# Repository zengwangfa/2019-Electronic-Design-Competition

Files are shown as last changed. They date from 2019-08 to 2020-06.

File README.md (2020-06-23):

# 纸张计数显示装置😄

<p align="center">
  <a href="/docs/论文/纸张计数显示器论文.md">电赛论文📚|</a>
  <a href="/software/">软件说明💻|</a>
  <a href="/mechanical/">机械说明🎮|</a>
  <a href="/hmi/">交互界面说明🖼|</a>
  <a href="/综合测评/">综合测评📐</a>
</p>

---

<p align="center">
  
</p>

<p align="center">
  
  
  
</p>

## 1、简介:pencil2:
>纸张计数显示装置基于**RT-Thread**实时操作系统，硬件平台采用**STM32F407**单片机为主控制器，以具有抗电磁干扰（**EMI**）架构的FDC2214模块作为电容采集传感器，通过**屏蔽双绞线**连接至两铜极板，读取采集的数据并进行相应判断，应用触摸屏和语音模块进行状态显示与播报。FDC2214模块将采集到的数据通过IIC协议传输给主控制器，主控制器对原始数据进行**卡尔曼滤波**，抑制噪声对数据采集的影响。校准模式下，本系统利用最大隶属度法，确定电容模拟值及纸张数的论域，定义模糊子集和隶属函数，建立模糊规则控制表，求得模糊控制查询表。其根据采集到的两极板的数据，做出短路判断并读取多组实时数据，将其与模拟区间进行归类，选取**最大可能性区间**作为期望值，减小最终判断的差错率。

- [x] 成果：在校准好后，50张以下`100%`正确

---

| 配置参数 | 主控制器 | 配置参数 | 主传感器 |
| :--: | :--: | :--: | :--: |
|芯片型号| STM32F407ZGT6 |芯片型号| FCD2214 |
|CPU| 32位 Cortex-M4(ARMv7) |分辨率| 28位 |
|主频| 168MHz |通道数| 4 |
|RAM| 192KB |接口| I2C |
|外存| 1MB(FLASH) |最高输出速率| 4.08ksps |
|单元| FPU、DSP | 特性 |抗电磁干扰(EMI) |

---

- 系统结构简图：
系统结构简图

## 2、目录说明:bookmark:

#### STM32F407控制程序在：
```
+——2019-Electronic-Design-Competition
|---+ software:【软件设计】
|       ├──README.md
|       ├──rt-thread-master
|            └──bsp
|               └──stm32f407【控制程序】
|                  └──project.uvprojx【Keil5工程】
|---- ...

```
| 目录名 | 描述  |
| :---: | :---: |
| 2019电赛题目| 2019年电赛A-H题题目及器件清单 |
| [docs](./docs/) | 数据手册、设计图片、参考文献及设计文档 |
| [hardware](./hardware/) | FDC2214、核心板原理图及PCB |
| hmi| 串口屏幕设计UI及交互程序、语音包 |
| matlab| matlab函数拟合及Kalman  |
| mechanical | 机械结构设计 |
| others | 一些关于电赛前的准备 |
| [**software**](./software/) | **纸张计数显示装置STM32程序** |
| [综合测评](./综合测评/) | **综合测评题目及Multisim电路仿真** |

## 3、[机械结构:hammer:](/mechanical/)
- 3维模型
3D效果图
- 实物图
铰链结构实物图

## 4、[软件说明💻](/software/) 

应用线程总体分为：
- 1.简单设备运行线程
    - LED
	- OLED
	- Buzzer
	- Flash
	
- 2.主测量应用线程
	- HMI屏幕交互
	- FD2214数据获取与转换
	- 语音模块交互
	
- 3.系统监控线程
	- Watch Dog:dog2:

## 5、硬件结构:artificial_satellite:

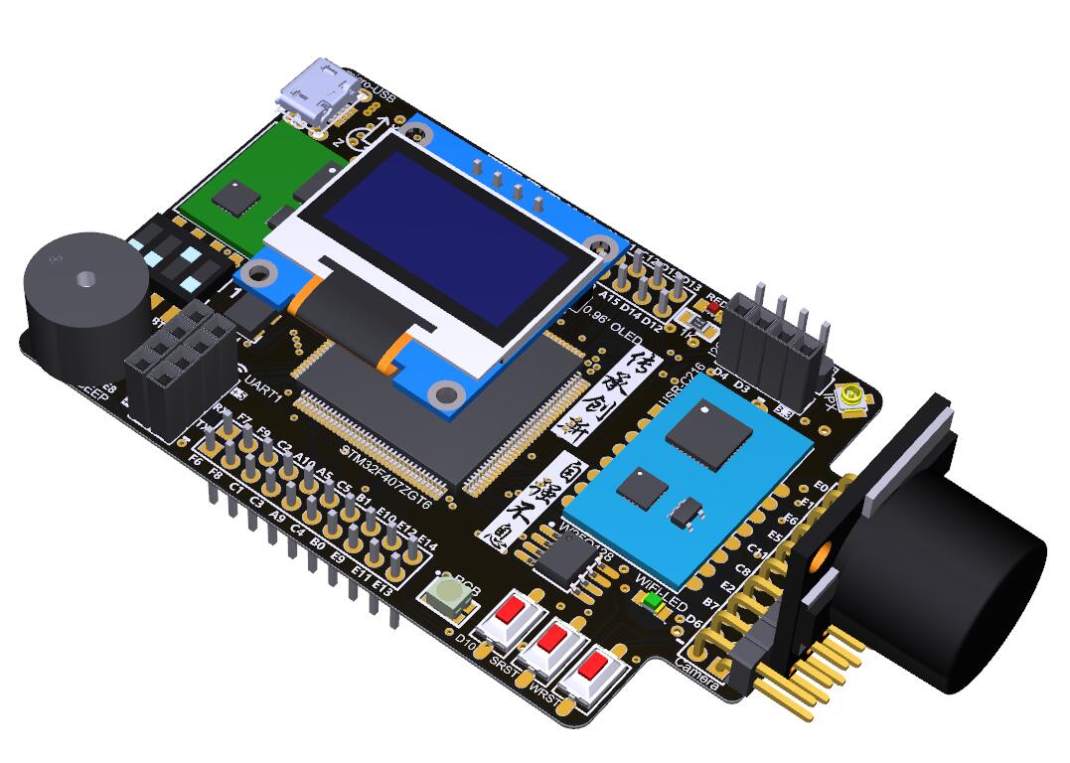
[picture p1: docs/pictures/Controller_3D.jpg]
Controller PCB 3D Core Controller 3D


- 核心板(Core Controller)拥有外设：

| 外设名称 | RGB LED | Key | Buzzer | Dial Switch | **FCD2214** | USART HMI |OLED | W25Q128 | Voltage Detection | Current Detection | Zigbee |  JY901 | USR-C216 | CP2102 |
| :---: | :---: | :---: | :---: | :---: | :---: | :---: | :---: | :---: | :---: | :---: | :---: | :---: | :---: |  :---: |
| 控制(通讯)方式 | GPIO | GPIO | GPIO | GPIO | **I2C** | USART | SPI | SPI | ADC | ADC | USART | USART | USART  | USART |
| 功能描述 | 指示灯 | 按键 | 蜂鸣器 | 拨码开关 | **电容传感器** | 串口触摸屏 | 显示屏 | 闪存芯片 | 电压检测 | 电流检测 | 2.4G无线通信 | 九轴 | WiFi模块 | 串口转USB |

- 整体实物图
整体实物图

---
## 6、[交互界面:framed_picture:](/hmi/) 

- [x] 电脑调试时的交互界面展示：

<p align="center">
  
</p>

## 7、测试数据分析:bar_chart:

(1)
保持测试环境不变，采集50个样本，通过MATLAB拟合出纸张页数与传感器原始数据的曲线关系，如图4-2所示。

拟合曲线

**图4-2 纸张页数与模拟量的拟合函数关系图**

- (2) 根据(1)中采集的50个样本，确定电容模拟值及纸张数的论域，划分模糊子集，如表4-1
所示。

**表4-1页数与模拟量区间对应表**

| 页数/张 | 对应模拟量区间 | 页数/张 | 对应模拟量区间  |
|---|---|---|---|
| 1 | [1680.00,1345.34] | 6 | [682.48,633.84] |
| 2 | [1345.34,1013.26] | 7 | [633.84,598.03] |
| 3 | [1013.26,845.12]  | 8 | [598.03,569.46] |
| 4 | [845.12,748.79] | 9 | [569.46,546.28] |
| 5 | [748.79,682.48] | 10 | [546.28,529.16] |

- (3)根据（2）中划分的模糊子集，保持测试环境不变，固定测量35张纸张，采集数据如表4-2所示，采集到的原始数据90%落入35张页数所对应的区间[401.35,399.50]，如图4-35

35张纸区间图 35页落点区间

**表4-2 纸张数为35的实时数据**

| 测试组别 | 原始数据 | 测试组别 | 原始数据 |
|---|---|---|---|
| 1 | 400.896  | 6 | 400.824  |
| 2 | 401.049  | 7 | 400.591  |
| 3 | 400.157  | 8 | 401.111  |
| 4 | 399.912  | 9 | 400.443  |
| 5 | 401.125  | 10 | 398.529  |

- 测试结果

**表4-4 工作模式下纸张测试结果表**

| 范围 | 测试次数 | 正确次数 | 正确率 |
|---|---|---|---|
| 1\~10  | 25 | 25 | 100% |
| 11\~20 | 25 | 25 | 100% |
| 20\~30 | 25 | 25 | 100% |
| 30\~40 | 25 | 25 | 100% |
| 40\~50 | 25 | 25 | 100% |
| 50\~60 | 25 | 23 | 92% |
| 60\~70 | 25 | 20 | 80% |
| 70\~80 | 25 | 16 | 64% |

## 8、[综合测评演练:triangular_ruler:](/综合测评/)
- 选定2017综合测评题目【符合信号发生器】，进行综合测评训练
2017年全国大学生电子设计竞赛综合测评题训练结果 2017年全国大学生电子设计竞赛综合测评题

虽然测评训练的时候做的还行，但是实际当天综测比赛的时候，还是会手忙脚乱，现在想起那天焊接电路颤抖的双手都有点好笑:rofl::rofl:。
- 综测训练测试结果：
2017综测训练

## 9、分工:family:
- [X] 电路设计
    - [X] 硬件搭建 by [@Ian](https://github.com/zengwangfa)	
	
- [X] 控制程序
    - [X] 整体框架 by [@Ian](https://github.com/zengwangfa)
	- [x] 交互界面及通信 by [@Ian](https://github.com/zengwangfa)
	- [X] 核心分割算法 by [@Okurarisona](https://github.com/Okurarisona)

- [X] 机械结构
	- [X] 结构方案设计 by [@JackyLin](https://github.com/JackyLin1205) 
	- [X] 固定铰链式抗干扰结构 by [@JackyLin](https://github.com/JackyLin1205) 

- [X] 论文
	- [X] 论文 by [@Hyf338](https://github.com/Hyf338)

#### Github下载过慢
- [Github下载过慢解决办法](https://blog.csdn.net/wangshuaiwsws95/article/details/104730741/)

#### 整理纪念
- [点击联系我](Mailto:zengwangfa@outlook.com)

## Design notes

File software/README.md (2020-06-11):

#### STM32F407控制程序在：
```
|---+ software:【软件设计】
|       ├──README.md
|       ├──rt-thread-master
|            └──bsp
|               └──stm32f407【控制程序】
|                  └──project.uvprojx【Keil5工程】
|---- ...

```

## 1. 程序描述与思路:book:

### 1.1 系统总体工作流程

> 软件部分主要分成用户交互设计以及数据处理算法设计，基于RT-Thread实时操作系统，利用系统的线程调度完成各个模块的程序处理，应用线程总体分为：

- 1.简单设备运行线程
    - LED
	- OLED
	- Buzzer
	- Flash
	
- 2.主测量引用线程
	- HMI屏幕交互
	- FD2214数据获取与转换
	- 语音模块交互
	
- 3.系统监控线程
	- Watch Dog

### 1.2 程序设计思路

> 在整体软件中，首先在触摸屏菜单进行人机交互，进入不同的功能调用不同的控制函数与数据处理算法。程序线程调度，主要分为简单任务以及核心算法算法任务。简单任务为IO设备、触摸屏、OLED屏幕、语音模块、NB-IOT模块等设备控制；核心控制算法任务为FDC2214电容模拟值采集、卡尔曼滤波以及模糊求解最大可能性落点区间，从而得到当前纸张数量。

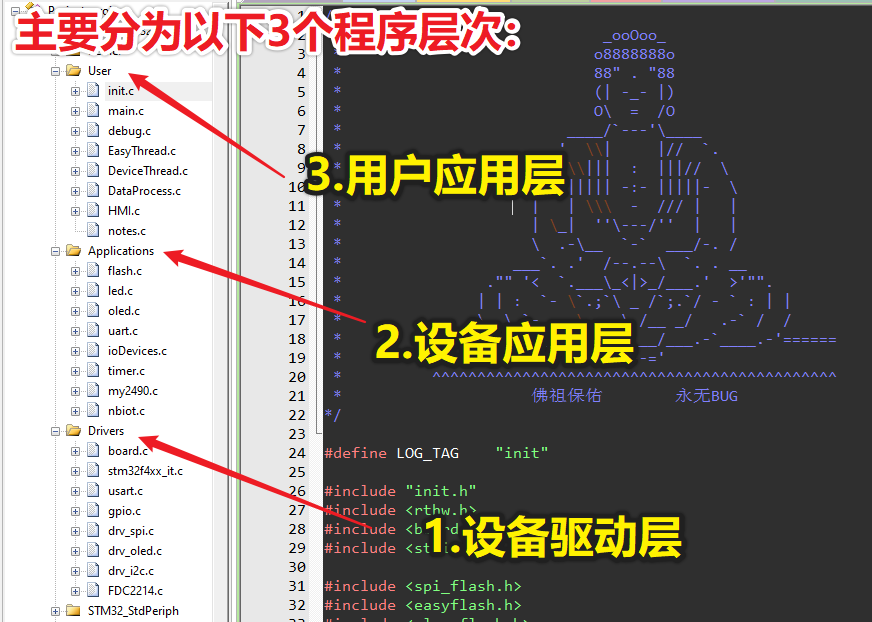
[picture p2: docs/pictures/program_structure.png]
程序结构


- [x] 1.首先在`设备驱动层`中构建好设备的底层硬件驱动程序，以供中层的`设备应用层`调用
- [x] 2.其次在`设备应用层`封装好相应的设备应用程序，留好相应的接口，以供上层`用户应用层`调用，例如：
	- **RGB LED**控制调用（参数：模式、颜色）
	- **蜂鸣器**控制调用（参数：响几声、响多长）
	- **语音模块**控制调用（参数：语音内容）
	- **OLED**控制调用（函数：显示对应的模式内容）
	- **Flash**控制调用（函数：读写参数）
	- **Uart**控制调用（函数：数据接收回调）
	- **FDC2214**控制调用（函数：获取电容值）
- [x] 3.最后在`用户应用层`中进行相应的**3.1 调试工具**、**3.2 模块交互封装**以及**3.3 数据处理**。

---
- 3.1 【调试工具】 在`debug.c`其中存放的为山外上位机示波器数据发送函数，用来分析数据较为合适。
	- eg:[这张图片是在调试PID与角度响应时所记录](../docs/pictures/debug.png "PID_debug")

- 3.2 【模块交互封装】 在`HMI.c`其中存放的为串口触摸屏的数据交互函封装(其中最重要的为：串口屏数据解析函数`HMI_Data_Analysis()`)

- 3.3 【数据处理】 最重要的为`DeviceThread.c`，其中存放工作模式的选择、运行线程以及调试
	- 1.数据校准：`FDC2214_Data_Adjust()`
	- 2.工作模式:`Capcity_Paper_Detection()`
	- 3.扩展功能模式：
		- ①打印机 纸张检测：`Printer_Paper_Detection()`
		- ②材料 检测：`Material_Detection()`
		- ③纸币 检测：`Money_Detection()`

- 工作模式选择，其与OLED页面对应
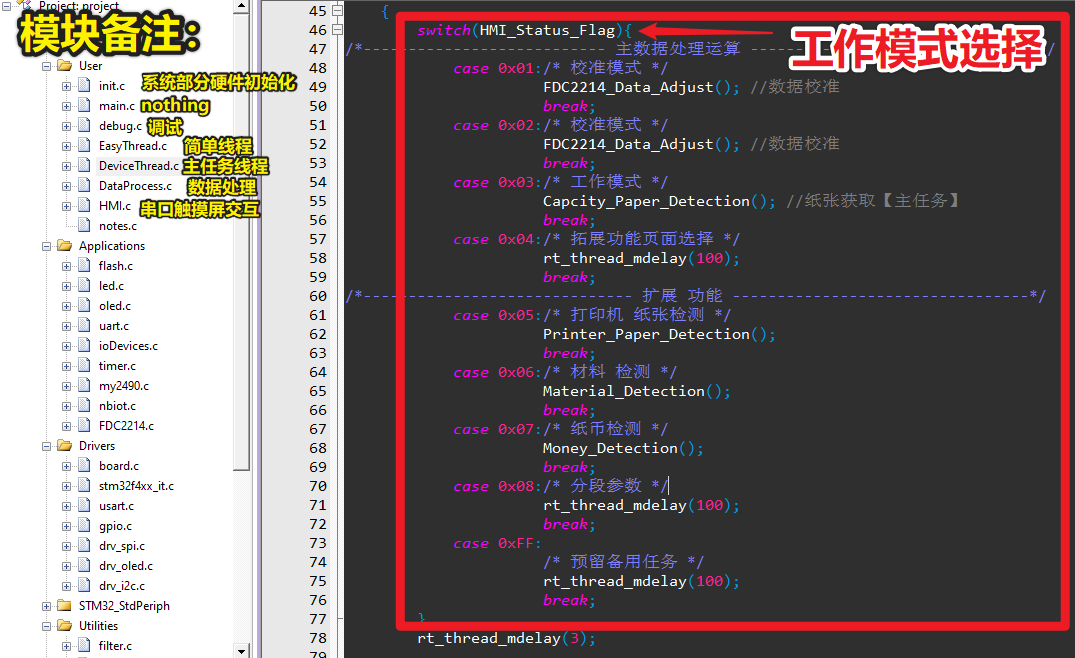
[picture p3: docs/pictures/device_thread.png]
工作模式选择


> 工作模式的选择来自于 变量`HMI_Status_Flag`，其为解析 触摸屏按钮所发出的数据包，而获得的工作模式。

## 2. 纸张数量程序的具体实现
### 2.1 获取电容值

1.首先准备就绪后，构建系统工作的参数结构体：
```c
typedef struct
{
	uint8 Status;      //检测时状态
	uint8 ShortStatus; //短路的状态
	uint8 Finish_Flag; //读取完成的标志
	uint8 PaperNumber; //纸张数量
	float Capacitance; //电容值
	
	int Time; //时间
}PaperCountEngine_Type;//纸张测数器状态
```
```c
//初始化变量Paper

PaperCountEngine_Type Paper = {
	.Finish_Flag = 2
};/*Paper数据结构体*/
```

> 用的是FDC2214第4通道，调用来自`设备应用层`的FDC采集函数，如下：
```c
/**
  * @brief  get_single_capacity 获取极板容值
  * @param  None
  * @retval 电容值
  * @notice 
  */
float get_single_capacity(void)
{
	static unsigned int res_CH4_DATA = 0;
	static float res_ch4 = 0.0f;
	
	FDC2214_GetChannelData(FDC2214_Channel_3, &res_CH4_DATA);
	res_ch4 = Cap_Calculate(&res_CH4_DATA);

	return res_ch4;
}
```

### 2.2 初始化电容值分割区间
> 根据FLASH中存入的电容值，划分区间
```c
/**
  * @brief  DataSubsection 电容值分割，获取区间
  * @param  Cap_Division电容切分后的值、arrey事先存入的电容值
  * @retval 
  * @notice 
  */
void DataSubsection(float Cap_Division[],float arrey[],int Number)
{

	static int rec = 1;
	
	for(int i = 2;i <= 30;i++){
		CapacitanceDP = (arrey[i-1]-arrey[i]) /2.0f;
		Cap_Division[i-1]= arrey[i-1]-CapacitanceDP;

	}
	for(int i=31;i<=40;i++){
		CapacitanceDP = Div_Parameter.Div_30_40*(arrey[i-1]-arrey[i]) /100.0f;
		Cap_Division[i-1]= arrey[i-1]-CapacitanceDP;
	}
	for(int i=41;i<=50;i++){
		CapacitanceDP = Div_Parameter.Div_40_50*(arrey[i-1]-arrey[i]) /100.0f;
		Cap_Division[i-1]= arrey[i-1]-CapacitanceDP;
	}
	
	for(int i=51;i<=60;i++){
		CapacitanceDP = Div_Parameter.Div_50_60*(arrey[i-1]-arrey[i]) /100.0f;
		Cap_Division[i-1]= arrey[i-1]-CapacitanceDP;
	}
	for(int i=61;i<=70;i++){
		CapacitanceDP = Div_Parameter.Div_60_70*(arrey[i-1]-arrey[i]) /100.0f;
		Cap_Division[i-1]= arrey[i-1]-CapacitanceDP;
	}
	for(int i=71;i<=80;i++){
		CapacitanceDP = Div_Parameter.Div_70_80*(arrey[i-1]-arrey[i]) /100.0f;
		Cap_Division[i-1]= arrey[i-1]-CapacitanceDP;
	}
	for(int i=81;i<=90;i++){
		CapacitanceDP = Div_Parameter.Div_80_90*(arrey[i-1]-arrey[i]) /100.0f;
		Cap_Division[i-1]= arrey[i-1]-CapacitanceDP;
	}				
	for(int i=91;i<=100;i++){
		CapacitanceDP = Div_Parameter.Div_90_100*(arrey[i-1]-arrey[i]) /100.0f;
		Cap_Division[i-1]= arrey[i-1]-CapacitanceDP;
	}				
	if(rec==1){
		Cap_Division[0] =arrey[1]+(arrey[1]-arrey[2]) /2.0f;
		rec = 0;
	}
}
```

### 2.3 根据区间推测落点

> 根据区间获取落点
```c
/**
  * @brief  ProbablityCapacitance 根据分割函数，获取可能的纸张数量
  * @param  50组电容值地址
  * @retval 电容值
  * @notice 按最大百分比返回对应的纸张数，因此只是可能值
  */
uint8 ProbablityCapacitance(float CompareArrey[])	//传入 需要比较的数据
{

	memset(Cap_Probability,0,sizeof(Cap_Probability));//清空电容值落点可能性

	for(int i=0;i <= Level;i++ ){
		for(int j=0; j<10 ;j++){
			if( (CompareArrey[j] < Cap_Division[i])  && (CompareArrey[j] >= Cap_Division[i+1])){
				Cap_Probability[i]++;
			}
		}
	}
	for(int n = 0;n < Level ;n++){
		if(Cap_Probability[n] > Cap_Probability[Probability_Max]){
			Probability_Max = (n + 1);
		}
		if(Cap_Probability[0] >= 5){	//纸张数的特殊处理
			Probability_Max = 1;
		}	
	}

	if(0 == Cap_Probability[Probability_Max-1]){
		Probability_Max = 0;
	}
	return Probability_Max;
}
```

### 2.4 转换为纸张数量

> 采集50组电容值数据，进行比较数据，获取最大可能性的落点
> 在比较数据，获取最终纸张数前，设置调度器上锁（上锁后，将不再切换到其他线程，仅响应中断），以防被打断造成数据出错
```c
void Get_Paper(void)
{
	for(int i = 0;i < 10;i++){
		Cap_Value[i] = get_single_capacity();//获取50组数据
	}	
    rt_enter_critical(); /* 调度器上锁 */
	Paper.PaperNumber = ProbablityCapacitance(Cap_Value);	//比较数据，获取最终 纸张数
    rt_exit_critical();	 /* 调度器解锁 */	 
}
```

## 3.串口触摸屏交互
### 3.1 串口屏返回数据解析
> 数据包格式如下：

| 编号 | 1 | 2 | 3 | 4 | 5 | 6 |
| :---: |:---: | :---: | :---: | :---: | :---: | :---: |
| 数据包所代表 | 包头1 | 包头2 | 数据包长度（不包括包头包尾及本身） | 工作模式位（页面） | 返回数据 | 累加和校验位 |
| 具体描述(16进制) | AA |55 | 02 | xx | xx | SUM |  

```c
/**
  * @brief  HMI_Data_Analysis(串口屏返回数据解析)
  * @param  控制字符数据 uint8 Data
  * @retval None
  * @notice 从第四个字节开始为数据字节
  */
void HMI_Data_Analysis(uint8 Data) //控制数据解析
{

	static uint8 i = 0;	   		  //
	static uint8 RxCheck = 0;	  //尾校验字
	static uint8 RxCount = 0;	  //接收计数

	hmi_data[RxCount++] = Data;	//将收到的数据存入缓冲区中

	if(RxCount <= (HMI_LEN+4)){ //定义数据长度未包括包头和包长3个字节,+4)  
		if(hmi_data[0] == 0xAA){ //接收到包头0xAA
			if(RxCount > 3){
				if(hmi_data[1] == 0x55){ //接收到包头0x55
					if(RxCount >= hmi_data[2]+4){ //接收到数据包长度位，开始判断什么时候开始计算校验
						for(i = 0;i <= (RxCount-2);i++){ //累加和校验
							RxCheck += hmi_data[i];
						}
		
						if(RxCheck == hmi_data[RxCount-1]){
							hmi_data_ok = 1; //接收数据包成功
						}
						else {
							hmi_data_ok = 0;
						}					
						RxCheck = 0; //接收完成清零
						RxCount = 0;	
						}
				}
				else {hmi_data_ok = 0;RxCount = 0;hmi_data_ok = 0;} //接收不成功清零
			}
		}
		else {hmi_data_ok = 0;RxCount = 0;hmi_data_ok = 0;} //接收不成功清零
	}
	else {hmi_data_ok = 0;RxCount = 0;hmi_data_ok = 0;} //接收不成功清零

	if(1 == hmi_data_ok){
		HMI_Status_Flag = hmi_data[3];//获取 工作模式位(页面)
		HMI_Data = hmi_data[4];//获取 返回的数据

		. /* 此处省略的为 数据解析后响应的处理函数 */
		.
		.
		.
		.
		. /* 此处省略的为 数据解析后响应的处理函数 */
	}
	hmi_data_ok = 0;
}
```

### 3.2 向串口屏发送纸张数量
```c

//76 61 31 2E 76 61 6C 3D 31 30 30 ff ff ff  va1.val=100
/* 该串数据用字符表达，即为： va1.val=100 */
uint8 him_uart_nmber_cmd[14] = {0x76,0x61,0x31,0x2E,0x76,0x61,0x6C,0x3D,0x31,0x30,0x30,0xff,0xff,0xff};
/*                                v    a   l     .   v     a    l    =   1     0    0      结束符     */

void uart_send_hmi_paper_numer(uint8 N_number)  //发送给hmi 纸张数量
{ 	

	him_uart_nmber_cmd[8]  = (N_number/100%10) + 0x30; //百位
	him_uart_nmber_cmd[9]  = (N_number/10%10) + 0x30; //十位
	him_uart_nmber_cmd[10] = (N_number/1%10) + 0x30;//个位

	rt_device_write(focus_uart_device, 0,him_uart_nmber_cmd	, sizeof(him_uart_nmber_cmd));	
}
```

## 4.程序流程图

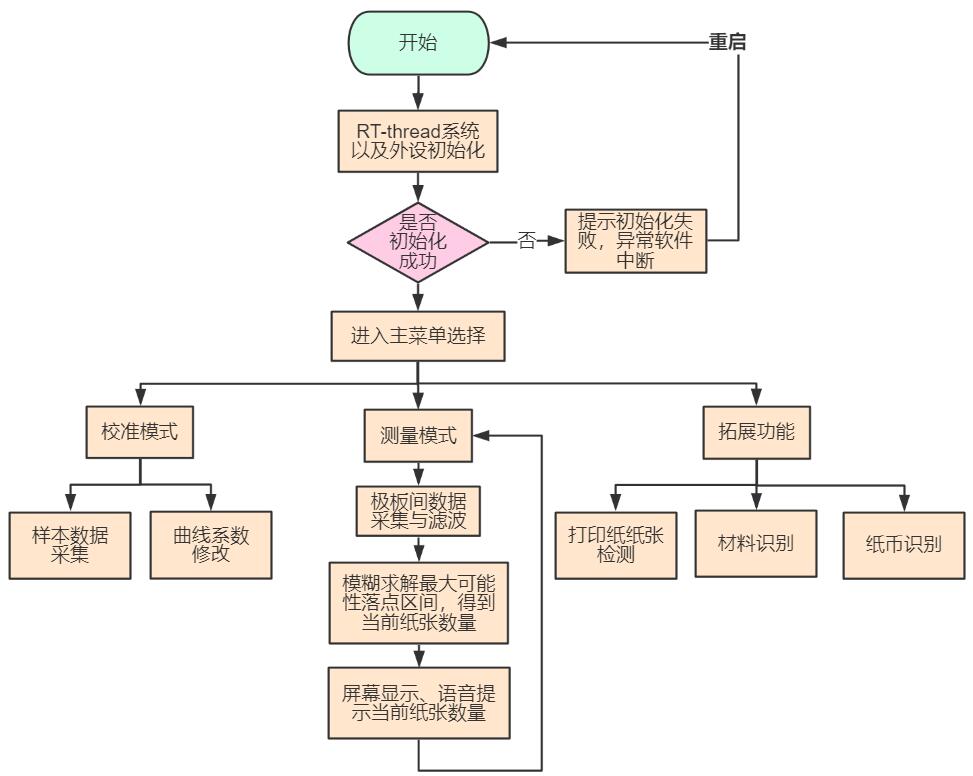
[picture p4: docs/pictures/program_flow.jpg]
程序流程图


## 5、测试数据分析

(1)
保持测试环境不变，采集50个样本，通过MATLAB拟合出纸张页数与传感器原始数据的曲线关系，如图4-2所示。

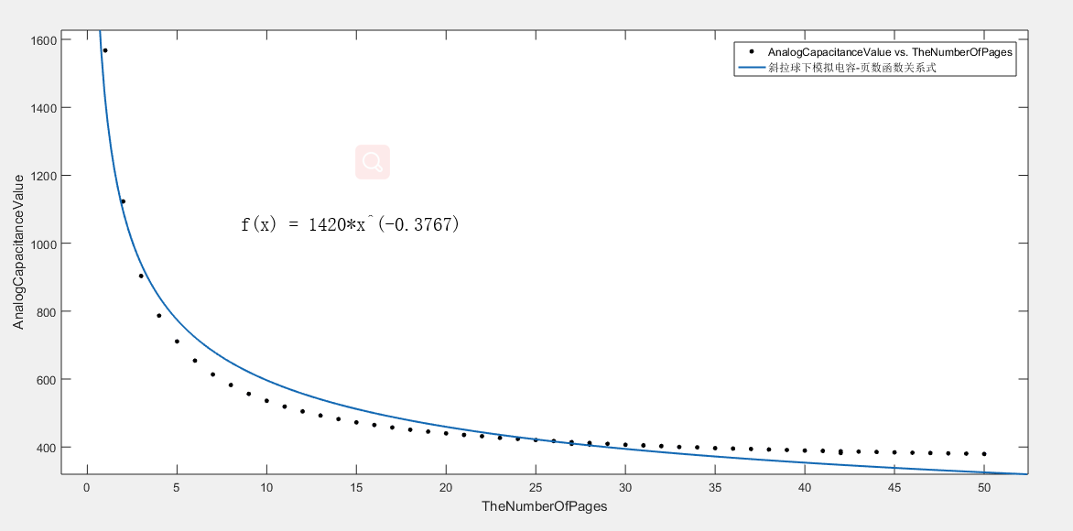
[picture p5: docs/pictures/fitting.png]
拟合曲线


**图4-2 纸张页数与模拟量的拟合函数关系图**

(2) 根据(1)中采集的50个样本，确定电容模拟值及纸张数的论域，划分模糊子集，如表4-1
所示。

**表4-1页数与模拟量区间对应表**

| 页数/张 | 对应模拟量区间 | 页数/张 | 对应模拟量区间  |
|---|---|---|---|
| 1 | [1680.00,1345.34] | 6 | [682.48,633.84] |
| 2 | [1345.34,1013.26] | 7 | [633.84,598.03] |
| 3 | [1013.26,845.12]  | 8 | [598.03,569.46] |
| 4 | [845.12,748.79] | 9 | [569.46,546.28] |
| 5 | [748.79,682.48] | 10 | [546.28,529.16] |

(3)
根据（2）中划分的模糊子集，保持测试环境不变，固定测量35张纸张，采集数据如表4-2所示，采集到的原始数据90%落入35张页数所对应的区间[401.35,399.50]，如图4-3所示。

程序流程图

**表4-2 纸张数为35的实时数据**

| 测试组别 | 原始数据 | 测试组别 | 原始数据 |
|---|---|---|---|
| 1 | 400.896  | 6 | 400.824  |
| 2 | 401.049  | 7 | 400.591  |
| 3 | 400.157  | 8 | 401.111  |
| 4 | 399.912  | 9 | 400.443  |
| 5 | 401.125  | 10 | 398.529  |

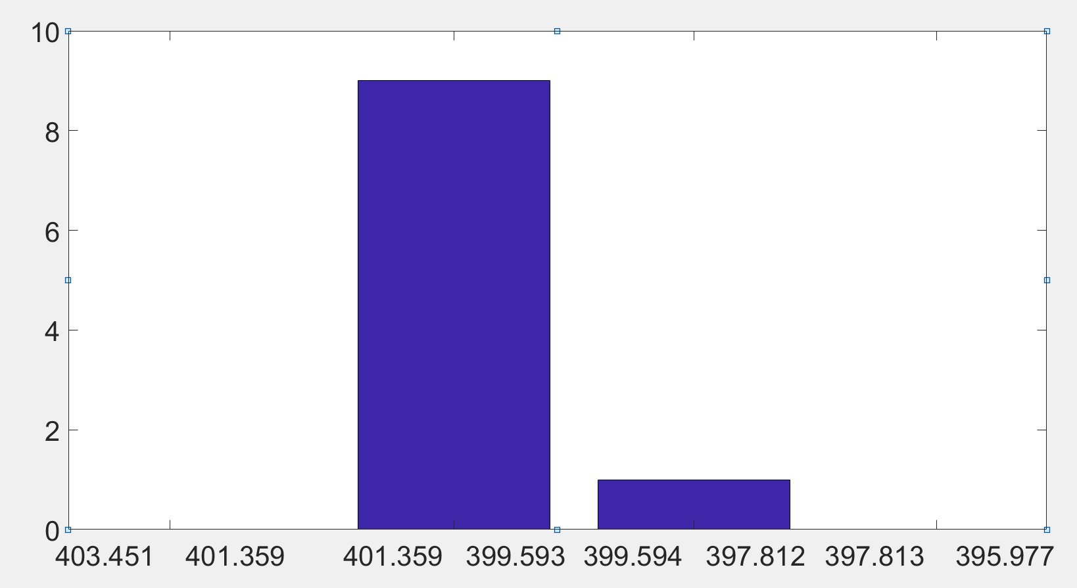
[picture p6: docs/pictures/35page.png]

>   **图4-3 纸张数为35的分布区间图**

(4)
根据（2）中划分的模糊子集，保持测试环境不变，固定测量46张纸张，采集数据如表4-3所示，模拟值大部分落入46张页数所对应的区间[383.6,382.7]，如图4-4所示。

**表4-3纸张数为46的实时数据**

| 测试组别 | 原始数据 | 测试组别 | 原始数据 |
|---|---|---|---|
| 1 | 383.1243 | 6 | 385.6523 |
| 2 | 383.7841 | 7 | 382.9651 |
| 3 | 384.1236 | 8 | 382.2015 |
| 4 | 384.3164 | 9 | 383.7621 |
| 5 | 383.9984 | 10 | 384.1343 |

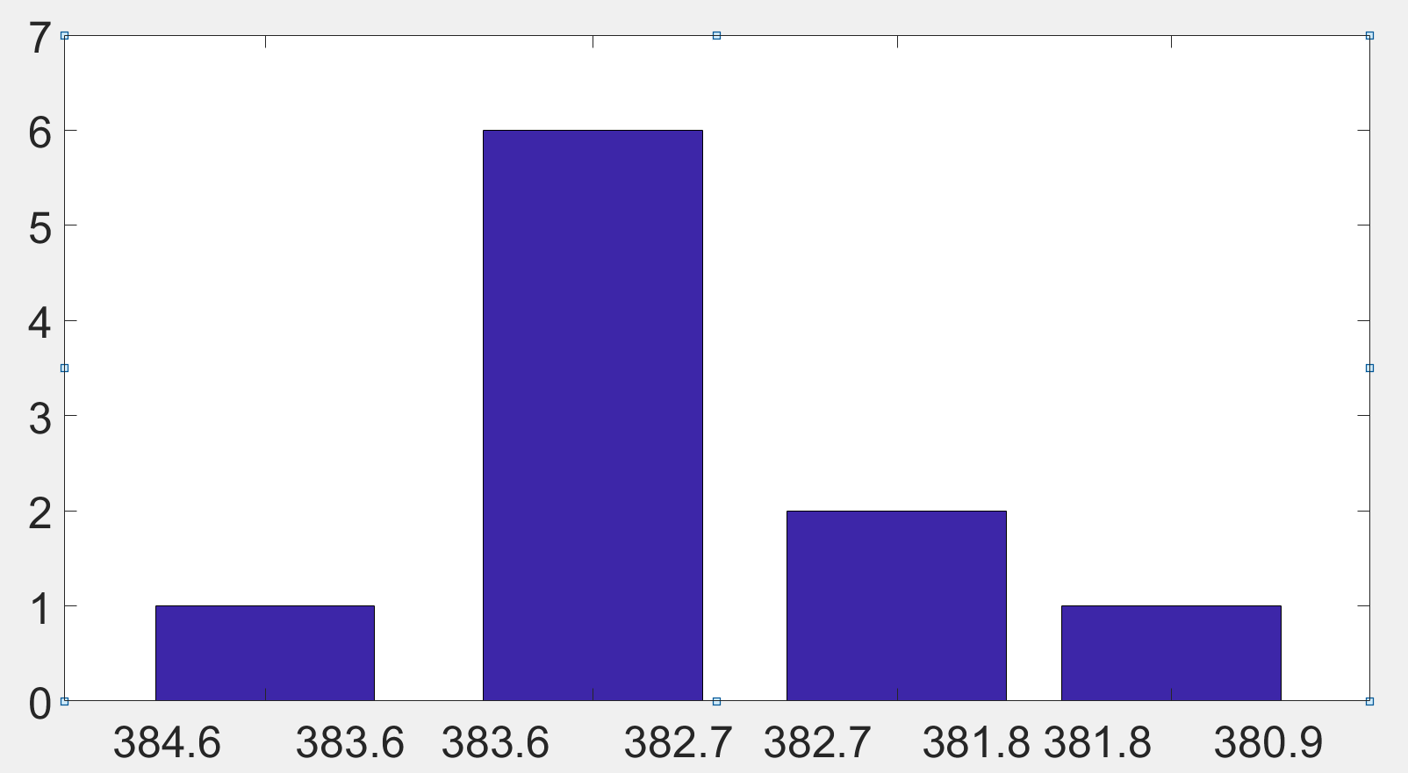
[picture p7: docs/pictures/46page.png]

**图4-4 纸张数为46的分布区间图**

- 测试结果

**表4-4 工作模式下纸张测试结果表**

| 范围 | 测试次数 | 正确次数 | 正确率 |
|---|---|---|---|
| 1\~10  | 25 | 25 | 100% |
| 11\~20 | 25 | 25 | 100% |
| 20\~30 | 25 | 25 | 100% |
| 30\~40 | 25 | 25 | 100% |
| 40\~50 | 25 | 25 | 100% |
| 50\~60 | 25 | 23 | 92% |
| 60\~70 | 25 | 20 | 80% |
| 70\~80 | 25 | 16 | 64% |

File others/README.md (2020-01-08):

# 纸张计数显示装置😄

<p align="center">
  <a href="https://zengwangfa.top/">个人主页🕺|</a>
  <a href="../docs/论文/纸张计数显示器论文.md">电赛论文📚|</a>
  <a href="../software/">软件说明💻|</a>
  <a href="../mechanical_structure/">机械说明🎮</a>
</p>

---

<p align="center">
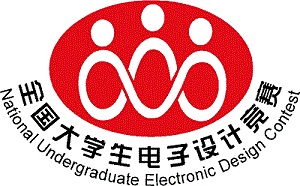
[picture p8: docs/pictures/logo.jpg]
  
</p>

<p align="center">
  
  
  
</p>

| 目录名 | 描述  |
| :---: | :---: |
| openMV | openMV设计程序 |
| software for development board | 纸张计数显示装置精简版 |
| software for rail gun | 电磁炮测试程序 |

### 赞赏
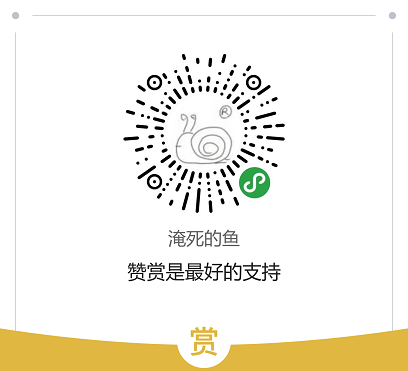
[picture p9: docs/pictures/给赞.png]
赞赏


#### 整理纪念
- [点击联系我](Mailto:zengwangfa@outlook.com)

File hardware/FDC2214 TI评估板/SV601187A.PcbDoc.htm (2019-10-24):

Reporting Options

# File in Previous Format

Date | : | 2019/8/7
Time | : | 14:47:06
Filename | : | D:\My\Github\2019 Electronic Design Competition\hardware\FDC2214 TI팀뮌겼\SV601187A.PcbDoc

Version | Warning

This file was generated by an earlier version of the software

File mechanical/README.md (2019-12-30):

方案一：重物压力式结构。如图1-1所示，利用重物，尽可能消除铜板和纸张间以及纸张之间的缝隙，并保证纸张厚度的统一，但该结构稳定性较差，对重物的摆放位置和模板的平衡性要求较高。

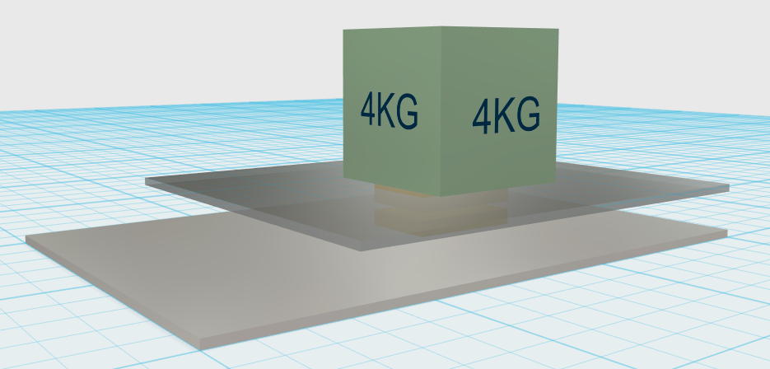
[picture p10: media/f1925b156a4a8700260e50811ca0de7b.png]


**图1-1 重物压力式结构示意图**

方案二：导轨式平压式结构。如图1-2所示，该结构确保每次纸张数量时以相同的结构特征进行数据采集，有利于对数据进行特征分析，并进行理论可行性的的论证，但是由于需要外接信号线导致平板高低不平，故而系统稳定性较差。

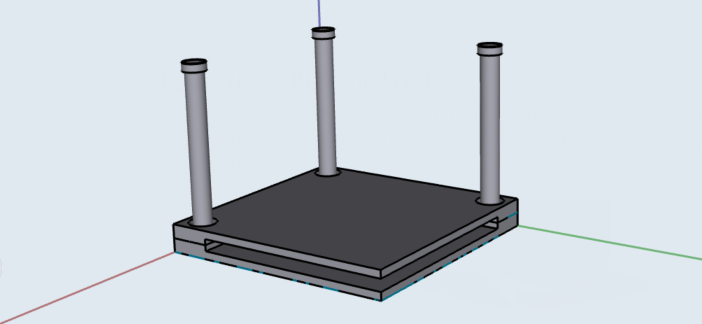
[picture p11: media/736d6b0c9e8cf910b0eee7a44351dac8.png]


**图1-2 导轨平压式结构示意图**

方案三：
固定铰链式抗干扰结构。如图1-3所示，通过拉动机械臂移动上极板，利用斜拉球缓冲垂直方向上的正压力，保证每次校验和测试时极板两侧压力相同，增加系统稳定性和测量上限。

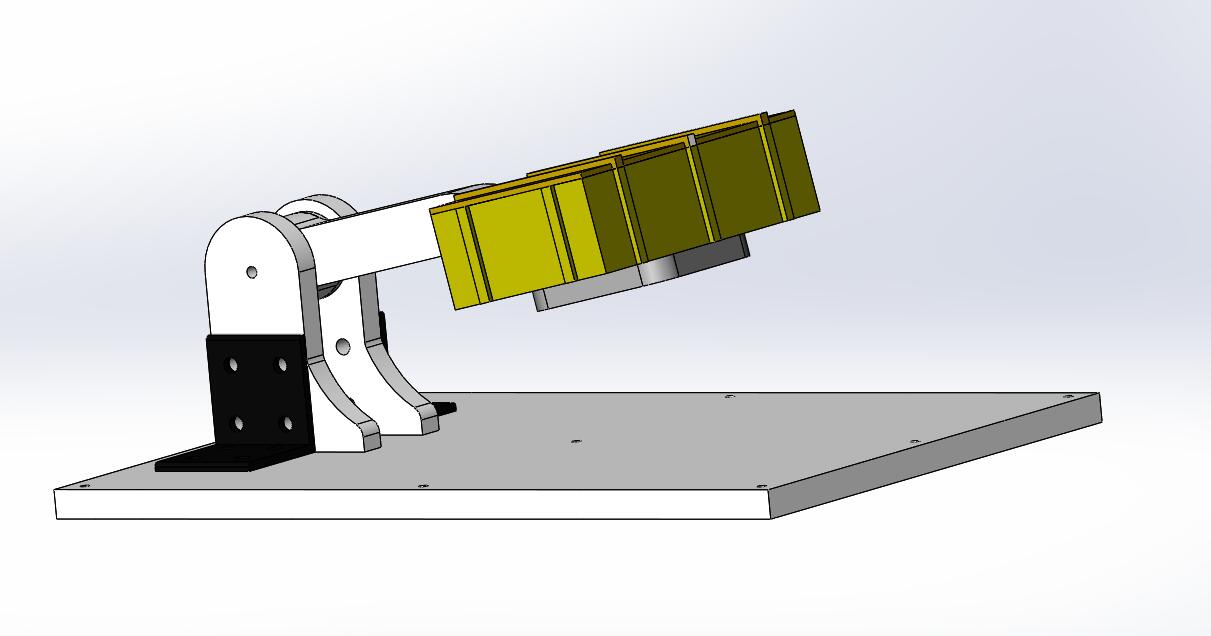
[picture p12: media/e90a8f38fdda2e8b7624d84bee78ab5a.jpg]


**图1-3 固定铰链式抗干扰结构示意图**

考虑到上下极板每次放置需要垂直正对，由于机械臂的位置固定，极板位置偏移量小，辅以斜拉球缓冲，综合考虑采用方案三。

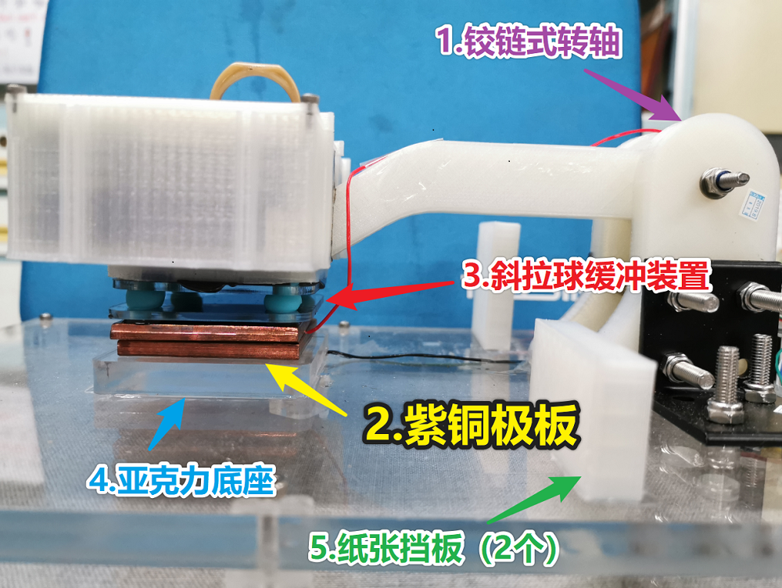
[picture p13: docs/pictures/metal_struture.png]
铰链结构实物图


- 整体实物图
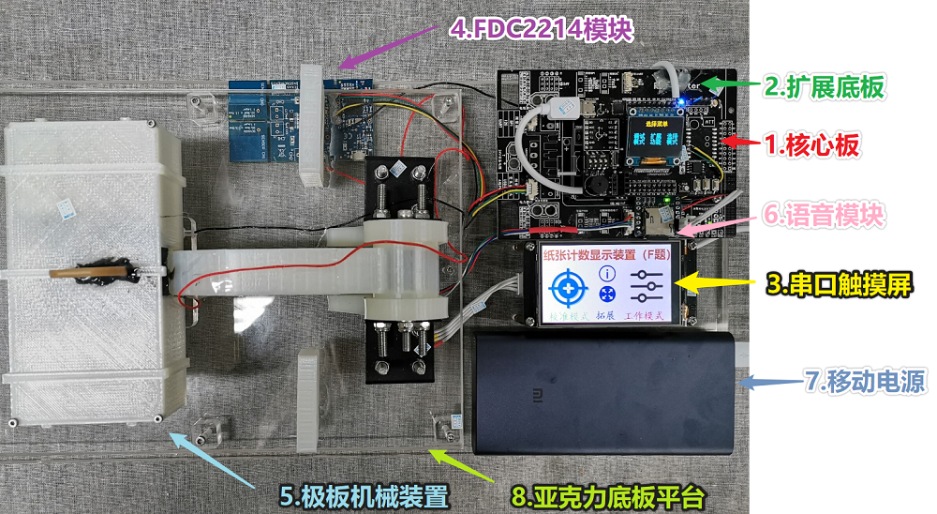
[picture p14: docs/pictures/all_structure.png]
整体实物图


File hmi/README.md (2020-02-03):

> 串口屏型号为 USART HMI 3.2寸增强型

- [x] 电脑调试时的交互界面展示：

<p align="center">
  
</p>

## 串口屏通讯协议
- [x] 以下数据格式都为`16进制`
- [x] 波特率：`115200`

控制字格式：0xAA 0x55 0x10+数据字节(2字节)+校验字(所有字节相加后，保留最后一个字节)

- 第1字节：包头位
- 第2字节：包头位
- 第3字节：数据长度位（不包括包头、自身的数据长度位和校验位，即为0x02）
- 第4字节：功能(页面)位
- 第5字节：数据位(代表该页面/功能的相关数据)
- 第6字节：累加和校验

| 编号| 1 | 2 | 3 | 4 | 5 | 6 | 
| :---: | :---: |  :---: |  :---: | :---: |  :---: | :---: |
| 含义 | 起始位 | 起始位 | 数据长度位 | 功能(页面)位 | 数据位  |校验位  | 
| 指令 | AA  | 55  | 02  | XX | XX  | SUM | 

| 页面编号 | 页面/功能含义 |
| :---: | :---: |
| 0 | 初始化页面 |
| 1 | 调试页面 |
| 2 | 调试页面下发送当前标定的是多少页 |
| 3 | 工作页面 |
| 4 | 拓展功能选择页面 |
| 5 | 打印机页面 |
| 6 | 材料判定页面 |
| 7 | 纸币设别 |
| 8 | 校准的页面参数设定 |

## 1.主界面
主界面分为：
- 1.校准模式
- 2.工作模式
- 3.拓展功能
- 4.关于（即“！”图标）

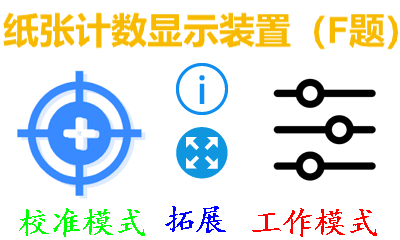
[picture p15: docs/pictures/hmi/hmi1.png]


## 2.校准模式界面
校准模式界面功能:写入每张纸对应的电容值，一进去默认为第0张（即红色圆框中的数值0），即“短路”状态下，按下“√”图标，即写入了“短路”时的电容值`C-short`，当判断是否“短路”时，则参考`C-short`的数值来判断。

当按下“+1”按钮，则红色圆框中的数值显示为1，即第1张纸开始校准，当放入第1张纸，再按下“√”图标，则写入第1张纸对应的的电容值。
... ...以此列推。

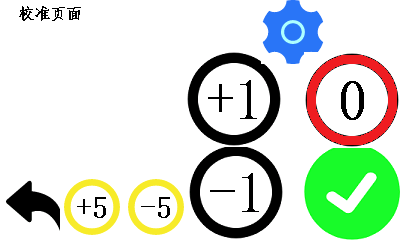
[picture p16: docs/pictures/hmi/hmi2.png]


## 3.区间参数值界面
> 按下2.校准模式界面 当中的“齿轮”图标得以进入

根据不同的区间划分了不同的百分比，可以根据当地的实际情况，灵活分配，从30-100，以10为间隔划分区间，默认为30%。

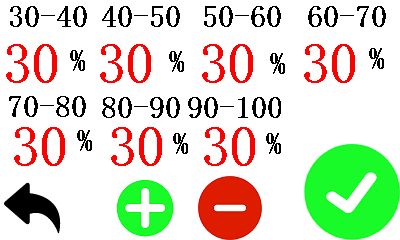
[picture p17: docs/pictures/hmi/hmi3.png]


## 4.工作模式界面
当按下右下角的红色“按钮”时，最上方会显示当前的纸张数量，以及会显示是否短路，如果短路，则绿色字体“是否短路”右侧会显示“是”，反之，则“否”。

“锁”图标为表示锁定状态，按下“锁”图标则“解锁”，会显示一个锁打开的图标
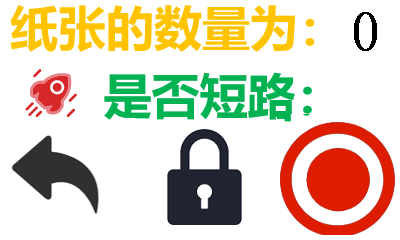
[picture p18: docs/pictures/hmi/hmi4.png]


## 5.上限阈值界面
当按下“火箭”图标，即上限+5，按“下降”图标，则-5，上限数值为右上数值

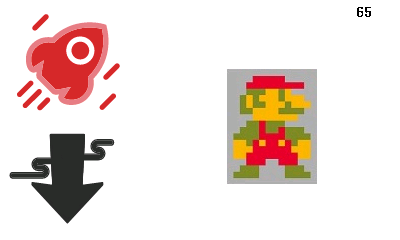
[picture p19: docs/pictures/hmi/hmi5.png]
上限阈值界面


## 6.拓展功能界面
拓展功能界面分为：
- 1.打印机纸盒检测
- 2.材料检测
- 3.纸币检测
> 以上拓展功能都较为重复，也只是一时兴起而做的一些拓展。

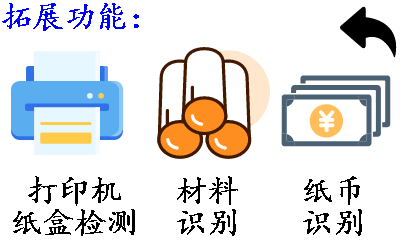
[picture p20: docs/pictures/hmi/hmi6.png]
拓展功能界面


## 7.打印机纸盒检测界面
纸张自动检测并显示在界面上，当纸张数量<5时，蜂鸣器报警提示，RGB快闪。

界面中“加”、“减”图标为修改纸盒的上限数值

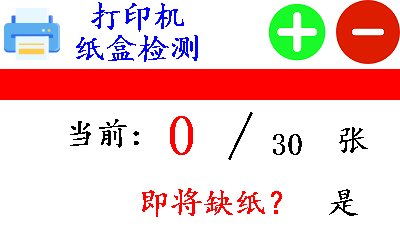
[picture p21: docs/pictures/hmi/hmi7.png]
打印机纸盒检测界面


## 8.材料检测界面
设定好两种材料：
- 1.KT板
- 2.纤维板

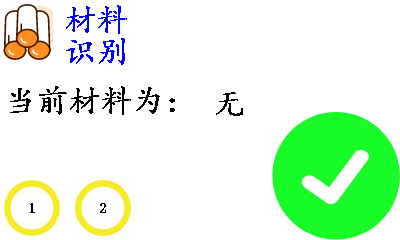
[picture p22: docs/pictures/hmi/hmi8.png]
材料检测界面


## 9.纸币检测界面
设定好纸币面额分别为：
- ￥5
- ￥10
- ￥50
- ￥100

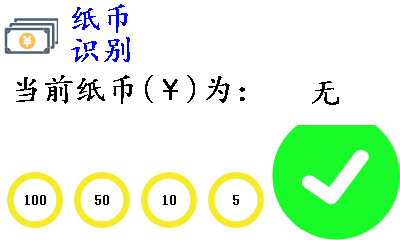
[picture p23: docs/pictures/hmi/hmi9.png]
纸币检测界面


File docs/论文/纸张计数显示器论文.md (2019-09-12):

2019年全国大学生电子设计竞赛

**纸张计数显示装置（F题）**

**【本科组】**

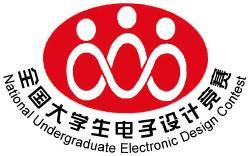
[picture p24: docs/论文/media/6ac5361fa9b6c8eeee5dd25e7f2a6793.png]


**JD046**

**2019年8月10日**

**摘 要**

纸张计数显示装置基于RT-Thread实时操作系统，硬件平台采用STM32F407单片机为主控制器，以具有抗电磁干扰（EMI）架构的FDC2214模块作为电容采集传感器，通过屏蔽双绞线连接至两铜极板，读取采集的数据并进行相应判断，应用触摸屏和语音模块进行状态显示与播报。FDC2214模块将采集到的数据通过IIC协议传输给主控制器，主控制器对原始数据进行卡尔曼滤波，抑制噪声对数据采集的影响。校准模式下，本系统利用最大隶属度法，确定电容模拟值及纸张数的论域，定义模糊子集和隶属函数，建立模糊规则控制表，求得模糊控制查询表。其根据采集到的两极板的数据，做出短路判断并读取多组实时数据，将其与模拟区间进行归类，选取最大可能性区间作为期望值，减小最终判断的差错率。

**关键字：** FDC2214 卡尔曼滤波 模糊算法 RT-Thread STM32

**Abstract**

This system is based on RT-Thread real-time operating system,the hardware
platform adopts STM32F407 microcontroller as the main controller,and FDC2214
module with anti-electromagnetic interference architecture as the capacitor
acquisition sensor.The FDC2214 module is connected to the two metal plates
through the shielded twisted pair,the collected data is sent back from the metal
plates to FDC2214 module,after being calculated,we use touch serial port screen
and voice module for state display and broadcast.FDC2214 module transport
collected data to the main controller through IIC protocol,The main controller
performs kalman filtering on the original data to reduce the influence of noise
on data collection.In the calibration mode, the system uses the mean of maximum
method to determine the theoretical domain of capacitance analog value and paper
number,define the fuzzy subset and membership function,establish the fuzzy rule
control table, and obtain the fuzzy control query table.According to the data
collected from the two metal plates,it makes short-circuit judgment and reads
multiple sets of real-time data,classifies them with the simulation
interval,selects the maximum probability interval as the expected value,and
reduces the error rate of the final judgment.

**Keyword:** FDC2214 Kalman Filtering Fuzzy Algorithm RT-Thread STM32

**目 录**

[1系统方案 1](#系统方案)

[1.1 电容式传感器的论证与选择 1](#电容式传感器的论证与选择)

[1.2 压力式结构的论证与选择 1](#压力式结构的论证与选择)

[1.3 控制系统模块的论证与选择 2](#控制系统模块的论证与选择)

[2系统理论分析与计算 2](#系统理论分析与计算)

[2.1 测量原理分析计算 2](#测量原理分析计算)

[2.1.1 创建模型：模拟平行极板电容器 2](#创建模型模拟平行极板电容器)

[2.1.2 FDC2214电容感测原理 3](#fdc2214电容感测原理)

[2.2 抗干扰分析 4](#抗干扰分析)

[2.2.1 卡尔曼滤波器 4](#卡尔曼滤波器)

[2.2.2 模糊算法 5](#模糊算法)

[2.3 误差分析 5](#误差分析)

[2.3.1 极板间充电效应 5](#极板间充电效应)

[2.3.2 不同环境下的电磁干扰 5](#不同环境下的电磁干扰)

[3电路与程序设计 6](#电路与程序设计)

[3.1电路的设计 6](#电路的设计)

[3.1.1系统总体框图 6](#系统总体框图)

[3.1.2 硬件电路整体框图 6](#硬件电路整体框图)

[3.2程序的设计 7](#程序的设计)

[3.2.1程序功能描述与设计思路 7](#程序功能描述与设计思路)

[3.2.2程序流程图 7](#程序流程图)

[4测试方案与测试结果 7](#测试方案与测试结果)

[4.1测试方案 7](#测试方案)

[4.2 测试条件与仪器 8](#测试条件与仪器)

[4.3 测试结果及分析 8](#测试结果及分析)

[4.3.1测试数据分析 8](#测试数据分析)

[4.3.2测试结果 9](#测试结果)

[4.3.3测试分析与结论 9](#测试分析与结论)

[5 创新特色总结展望 9](#创新特色总结展望)

[6.参考文献 9](#参考文献)

[附录1：电路原理图 10](#附录1电路原理图)

[附录2：源程序 10](#附录2源程序)

**纸张计数显示装置（F题）**

**【本科组】**

1系统方案
=========

本系统主要由电容式传感器模块、机械结构、控制系统组成，下面分别论证这几个模块的选择。

1.1 电容式传感器的论证与选择
----------------------------

方案一：基于NE555时基电路的电容式传感器测量电路。由电容式传感器和NE555实际电路构成多谐振荡器，将电容转化为频率，使电容的极距与频率形成正比，在通过F/V频率转换器转换成电压，由减法器输出与极板位移相应的电压。

方案二：FDC2214电容数字转换器。FDC2214采用创新型抗EMI架构，具有28位分辨率，4.08ksps高输出速率，可对噪声和干扰进行高度抑制。具有低功耗，4通道的接触式感测技术，支持宽激励频率范围，可为系统设计带来灵活性。

考虑题目对测量精度的要求，电容式传感器应用灵敏度的主要限制因素在于传感器的噪声敏感性，
FDC2214采用创新型EMI架构，即使在高噪声环境中也能维持性能不变。综合考虑采用方案二。

1.2 压力式结构的论证与选择
--------------------------

方案一：重物压力式结构。如图1-1所示，利用重物，尽可能消除铜板和纸张间以及纸张之间的缝隙，并保证纸张厚度的统一，但该结构稳定性较差，对重物的摆放位置和模板的平衡性要求较高。



**图1-1 重物压力式结构示意图**

方案二：导轨式平压式结构。如图1-2所示，该结构确保每次纸张数量时以相同的结构特征进行数据采集，有利于对数据进行特征分析，并进行理论可行性的的论证，但是由于需要外接信号线导致平板高低不平，故而系统稳定性较差。



**图1-2 导轨平压式结构示意图**

方案三：
固定铰链式抗干扰结构。如图1-3所示，通过拉动机械臂移动上极板，利用斜拉球缓冲垂直方向上的正压力，保证每次校验和测试时极板两侧压力相同，增加系统稳定性和测量上限。



**图1-3 固定铰链式抗干扰结构示意图**

考虑到上下极板每次放置需要垂直正对，由于机械臂的位置固定，极板位置偏移量小，辅以斜拉球缓冲，综合考虑采用方案三。

1.3 控制系统模块的论证与选择
----------------------------

方案一：选用AT89C51作为主控制器。AT89C51为8位单片机，数据处理能力明显不足。

方案二：TI公司的MSP430系列微控制器。MSP430单片机具有低功耗的特点，但相较于32位单片机的接口外设及内存资源较少

方案三：STM32系列微控制器。高性能、外设接口及内存资源丰富，用户基数大，资料相对较多。

本系统的需采集的数据样本较为庞大，综合考虑采用方案三。

2系统理论分析与计算
===================

2.1 测量原理分析计算 
---------------------

###  创建模型：模拟平行极板电容器

本装置利用两个平行极板模拟平行极板电容器，装置结构简图如图2-1所示：

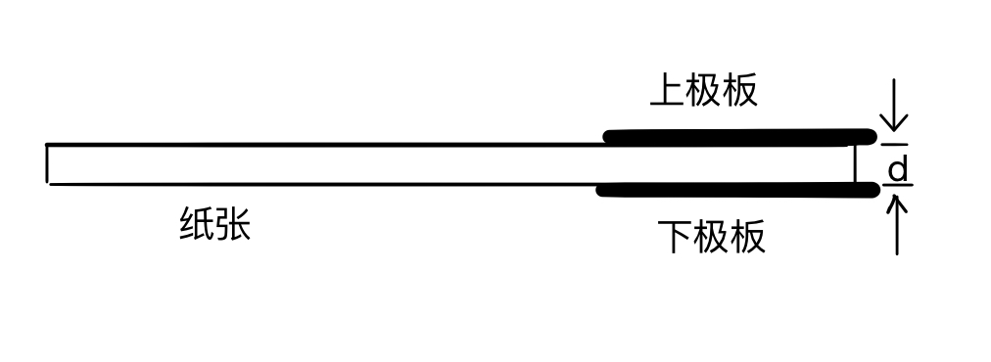
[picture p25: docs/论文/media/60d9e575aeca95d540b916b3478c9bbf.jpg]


**图2-1 平行极板装置示意图**

平板电容器的电容为







（式2-1）

上下极板之间紧夹被测纸张，待测纸张厚度等于上下极板间距离d，极板面积S和相对介电常数保持不变，=8.85，改变极板间待测纸张的数量，电容C边随之变化。

###  FDC2214电容感测原理

FDC2214是基于LC谐振电路原理的一个电容检测传感器，其模块模块原理图如图2-2所示。



**图2-2 FDC2214传感模块电路**

在芯片每个检测通道的输入端连接一个电感和电容，组成LC电路。典型选择是18uH屏蔽SMD电感与33pF电容并联。被测电容传感端与LC电路相连接，将产生一个振荡频率，根据频率值可计算出被测电容值。

FDC2214传感器频率表示为：



（式2-1）

其中：DATAx：DATA_CHx寄存器的转换结果；

fREFX：通道x的参考频率；

FDC2214的数据输出（DATAx）表示为：



（式2-2）

FDC2214传感器测量的传感电容表示为：



（式2-3）

改变极板间距，导致极板间的电容值发生了变化，从而引起LC电路振荡频率的变化，根据频率值可知平行极板之间的传感器原始数据。

2.2 抗干扰分析 
---------------

###  卡尔曼滤波器



**图2-3 卡尔曼滤波器**

卡尔曼滤波器是一个“optimal recursive data processing
algorithm”（最优化自回归数据处理算法）。卡尔曼滤波器通过对过程状态进行估计，卡尔曼滤波器可以分为时间更新和测量更新两个部分：时间更新部分负责向前推算当前的状态变量和误差协方差的估计值，构造下一个时间状态的先验估计；测量更新部分负责信息反馈，用先验估计和新的测量变量构造新的后验估计。





**图2-4 采样数据与KLM滤波数据对比图 图2-5 采样误差与KLM估计误差对比图**

由图2-3的测试结果可知，在测试过程中，主控制器采集到的数值波动较大，排除外部可能造成的干扰，系统本身的采样过程中引入了白噪声，这里通过卡尔曼滤波除去信号中的噪声干扰。

在一个周期内对系统采样50次，将其中一组数据经过卡尔曼滤波后可以看到估计值相较原始数据，波动更小，数据更加平顺。

由图2-4的测试结果可知，在纸张数量一定的情况下，计算在理想情况下（无噪声干扰）的理论真值，以理论真值为参照，比较采集值与经过滤波后的估值与真值的误差，可以看到经过过卡尔曼滤波后的数据误差更小。

### 2.2.2 模糊算法

模糊推理算法是指通过对现实对象的分析，处理数据并构建模糊数学模型。模糊算法是逐次求精的过程。



**图2-5 模糊控制系统组成**

在模糊控制中有多重解模糊的方式：面积平分法、加权平均法（重心法）、平均最大隶属度法等。根据系统的特性，我们选用平均最大隶属度法进行解模糊运算。

最大隶属度法具有两大原则：

　　第一,穷尽性原则,即对象总体中所有分子都能归类。

　　第二,排它性原则,即对象总体中任何一个分子都不能同时归属于两个或者更多的类。

模糊推理结果为输出论域上的模糊集，通过平均最大隶属度法，取模糊集中具有最大隶属度的所有点的平均值作为去模糊化的结果，由此可得到论域上的精确值。

2.3 误差分析 
-------------

###  极板间充电效应

经过多次试验测试分析，当极板长时间处于未处于短路状态下，电容极板会产生充电效应，导致极板间电容逐渐增大，对传感器原始数据的采集造成影响，如表2-1所示。当纸张页数较高时，影响尤为明显，如表2-2所示。

**表2-1 在20张纸条件下传感器原始数据变化表**

| 充电时间/s | 0 | 5 | 10 | 15 | 20 | 60 |
|---|---|---|---|---|---|---|
| 传感器原始数据 | 424.74 | 424.75 | 424.73 | 424.83 | 424.89 | 424.91 |

**表2-2 在65张纸条件下传感器原始数据变化表**

| 充电时间/s | 0 | 5 | 10 | 15 | 20 | 60 |
|---|---|---|---|---|---|---|
| 传感器原始数据 | 351.94 | 352.10 | 352.17 | 352.32 | 352.41 | 353.21 |

###  不同环境下的电磁干扰

考虑到不同环境下会对装置产生不同的电磁干扰，因此进行多种环境下的测试，测量结果如下。可明显看出不同环境下电磁干扰对采集的原始数据造成干扰。

**表2-3 不同环境下采集的传感器原始数据**

| 页数 | 10 | 15 | 20 | 25 | 30 |
|---|---|---|---|---|---|
| 木质桌面 | 516.824 | 452.027 | 418.502 | 399.327 | 385.927 |
| 水泥地板 | 524.529 | 460.381 | 427.152 | 407.870 | 394.625 |

3电路与程序设计
===============

3.1电路的设计
-------------

### 系统总体框图



**图3-1 系统总体框图**

###  硬件电路整体框图



**图3-2硬件电路整体框图**

3.2程序的设计
-------------

### 程序功能描述与设计思路

（1）系统总体工作流程

软件部分主要分成用户交互设计以及数据处理算法设计，基于RT-Thread实时操作系统，利用系统的线程调度完成各个模块的程序处理，程序流程图如图3-3所示。

（2）程序设计思路

在整体软件中，首先在触摸屏菜单进行人机交互，进入不同的功能调用不同的控制函数与数据处理算法。程序线程调度，主要分为简单任务以及核心算法算法任务。简单任务为IO设备、触摸屏、OLED屏幕、语音模块、NB-IOT模块等设备控制；核心控制算法任务为FDC2214电容模拟值采集、卡尔曼滤波以及模糊求解最大可能性落点区间，从而得到当前纸张数量。

### 3.2.2程序流程图



**图3-3 程序流程图**

4测试方案与测试结果
===================

4.1测试方案
-----------



**图4-1 测试流程图**

4.2 测试条件与仪器
------------------

（1）软件开发环境：Keil5。

（2）配套加工安装条件：3D打印机，激光切割机。

（3）前期自行设计使用模块：主控制器核心控制板。

4.3 测试结果及分析
------------------

### 测试数据分析

(1)
保持测试环境不变，采集50个样本，通过MATLAB拟合出纸张页数与传感器原始数据的曲线关系，如图4-2所示。



**图4-2 纸张页数与模拟量的拟合函数关系图**

(2) 根据(1)中采集的50个样本，确定电容模拟值及纸张数的论域，划分模糊子集，如表4-1
所示。

**表4-1页数与模拟量区间对应表**

| 页数/张 | 对应模拟量区间 | 页数/张 | 对应模拟量区间  |
|---|---|---|---|
| 1 | [1680.00,1345.34] | 6 | [682.48,633.84] |
| 2 | [1345.34,1013.26] | 7 | [633.84,598.03] |
| 3 | [1013.26,845.12]  | 8 | [598.03,569.46] |
| 4 | [845.12,748.79] | 9 | [569.46,546.28] |
| 5 | [748.79,682.48] | 10 | [546.28,529.16] |

(3)
根据（2）中划分的模糊子集，保持测试环境不变，固定测量35张纸张，采集数据如表4-2所示，采集到的原始数据90%落入35张页数所对应的区间[401.35,399.50]，如图4-3所示。



**表4-2 纸张数为35的实时数据**

| 测试组别 | 原始数据 | 测试组别 | 原始数据 |
|---|---|---|---|
| 1 | 400.896  | 6 | 400.824  |
| 2 | 401.049  | 7 | 400.591  |
| 3 | 400.157  | 8 | 401.111  |
| 4 | 399.912  | 9 | 400.443  |
| 5 | 401.125  | 10 | 398.529  |

>   **图4-3 纸张数为35的分布区间图**

(4)
根据（2）中划分的模糊子集，保持测试环境不变，固定测量46张纸张，采集数据如表4-3所示，模拟值大部分落入46张页数所对应的区间[383.6,382.7]，如图4-4所示。



**表4-3纸张数为46的实时数据**

| 测试组别 | 原始数据 | 测试组别 | 原始数据 |
|---|---|---|---|
| 1 | 383.1243 | 6 | 385.6523 |
| 2 | 383.7841 | 7 | 382.9651 |
| 3 | 384.1236 | 8 | 382.2015 |
| 4 | 384.3164 | 9 | 383.7621 |
| 5 | 383.9984 | 10 | 384.1343 |

**图4-4 纸张数为46的分布区间图**

### 4.3.2测试结果

**表4-4 工作模式下纸张测试结果表**

| 范围 | 测试次数 | 正确次数 | 正确率 |
|---|---|---|---|
| 1\~10  | 25 | 25 | 100% |
| 11\~20 | 25 | 25 | 100% |
| 20\~30 | 25 | 25 | 100% |
| 30\~40 | 25 | 25 | 100% |
| 40\~50 | 25 | 25 | 100% |
| 50\~60 | 25 | 23 | 92% |
| 60\~70 | 25 | 20 | 80% |
| 70\~80 | 25 | 16 | 64% |

### 4.3.3测试分析与结论

根据上述测试数据可知，采集到的原始数据与纸张数大致呈幂函数关系，通过划分模糊子集，修改模糊规则控制表，确定每个区间的隶属度，可推算出当前的纸张数量。

经测试，该系统可实现题设要求的全部功能，且误差在题目要求范围之内。

5 创新特色总结展望 
===================

本系统在完成了题目要求的同时，还增加触摸屏进行人机交互，具有十分友善的GUI，并增加了语音提示功能。系统的稳定测量源于机械结构的创新特性，采用固定铰链式抗干扰结构，确保上下极面的正对面积保持不变。整个系统的构建源于机械结构、电路设计、软件设计的合理架构，最大亮点是基于RT-Thread实时操作系统进行线程调度，极大程度的利用了MCU的资源，使得系统响应快、稳定性高。此外，基于电容检测的特性，增加了扩展功能以适应一些生活应用场景，例如：打印机剩余纸张检测，当纸张数量小于一定数量，报警提示用户；材料识别，预先采集材料阈值，进行不同材料的区分；纸币识别，识别不同纸币的面额。

6.参考文献 
===========

| [1]德州仪器半导体技术（上海）有限公司. 德州仪器高性能模拟器件高校应用指南.德州仪器半导体技术（上海）有限公司大学计划, 2014.
|---------------------------------------------------------------------------------------------------------------------------------------------------------------------------|

| [2]彭丁聪.卡尔曼滤波的基本原理及应用[J].软件导刊,2009,8(11):32-34. 
|---------------------------------------------------------------------------------------------------------------------------------------------------------------------------|

| [3]刘尧,邱运鹏,裴成梅,汪晨阳,胡安正.基于FDC2214电容式传感器的手势识别装置[J]. 电子制作,2019(10):13-15. |
|---------------------------------------------------------------------------------------------------------------------------------------------------------------------------|

附录1：电路原理图
=================


==========================================

附录2：源程序
=============

核心函数：计算最大可能落点，返回纸张页数



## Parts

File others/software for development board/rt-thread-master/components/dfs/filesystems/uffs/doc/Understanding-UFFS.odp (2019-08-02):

## Understanding UFFS

Ricky Zheng

< ricky_gz_zheng@yahoo.co.nz >

Created: March 2007

Last modified: Nov 2011

## Content

- Why UFFS ?
- Design goal
- Flash: NOR vs NAND ?
- What's wrong with FAT ?
- UFFS basic idea
  - Serial number
  - Tree in memory
  - Journalizing
- UFFS architecture
  - UFFS device
  - Mount point
  - UFFS nodes tree
  - Mounting UFFS
  - Page spare/UFFS tags
  - Block info cache
  - UFFS page buffer
  - Block recover
  - Bad block management
  - How ECC works ?
  - Flash interface
- What's next ?
  - UFFS2

## Why UFFS ?

- JFFS/JFFS2
  - Can't go out of Linux/MTD
  - Memory monster
- YAFFS/YAFFS2 still consumes too much RAM
  - 64M FLASH, 500 files ==> 410K RAM
- No open source lightweight flash file system exists yet ...

## UFFS design goal

- Ultra low cost
  - Low memory cost
  - Fast booting
- Superb Stability
  - Constant RAM consumption, support static memory allocation
  - Guaranteed integrity across unexpected power losses
  - Bad block tolerant, ECC and ware leveling
- NAND flash friendly
  - Support small (512B) or large page (up to 4KB) size
  - Support SLC and MLC
  - Support software ECC or hardware ECC / RS-ECC
  - Direct flash interface
- Well Emulated on PC platform, easy for debugging

## Flash: NOR vs NAND

- NOR:
  - Random access for read
  - Big block (minimal erase unit)
  - Byte programing
  - Slow erasing/programing
- NAND:
  - Page/spare access for read
  - Small block
  - Page/spare programing (with limited splits/Restricted rewrite)
  - Fast erasing/programing
  - Delivered with bad blocks

## NAND Flash Basic

Page data

Spare

Block

Erase: '0'->'1', Write/Program: '1'->'0'

## What's wrong with FAT

- Need FTL (which may cost many RAM)
- Big FAT table,slow down the whole system
- Vulnerable when unexpectedly interrupted while updating FAT or File info

FAT

File info

Changes

Write File

Changes

File data

Changes

## UFFS basic idea(1)

Parent

Serial

Parent

Serial

Parent

Serial

Parent

Serial

Parent

Serial

Parent

Serial

Parent

Serial

Parent

Serial

Parent

Serial

- Use unique parent/serial number pair to:
  - Identify blocks
  - Build relationships

ROOT

Parent: 16 bit

Serial: 16 bit

## UFFS basic idea(2)

- Build the relationship tree in memory when mounting UFFS:
  - Erased blocks
  - Bad blocks
  - Hash tables (serial number as key)
    - Dir table
    - File table
    - File data table
- Tree node size: 16 bytes
  - Memory cost: 16 * total_blocks

## UFFS basic idea(3)

- Journalizing
  - Write to a new block/page instead of modify the old one.
  - Use circular time stamp: 00->01->11->00>...
  - Check and correct conflicts while mounting UFFS
  - Using “mini-header” eliminates partial page programing requirement

## UFFS Device

- UFFS Device & Mount Point

extern uffs_Device uffs_rootDev;

extern uffs_Device uffs_dataDev;

static struct uffs_mountTableSt femu_MountTbl[] = {

{&uffs_rootDev, 0, 200, "/"},

{&uffs_dataDev, 201, -1, "/data/"},

{NULL, 0, 0, NULL},

};

“/”

“/data/”

UFFS Device ===> Partition
UFFS Device: individual flash ops, cache/buffer, tree nodes ...

## UFFS node tree

- UFFS nodes tree

UFFS device

Bad blocks

Erased blocks

Dir nodes

File nodes

Data nodes

Hash table, serial as the key

block,next

block,next

block,parent,serial,sum,next

block,parent,serial,sum,length(4),next

block,parent,serial,length(2),next

sizeof(TreeNode) = 16B

## UFFS Mounting

- Mounting UFFS

Step 1:

  - Scan page spares*, classify DIR/FILE/DATA nodes
  - Check bad block
  - Check interrupted writing

Step 2:

  - Randomize erased blocks

Step3:

  - Check DATA nodes,take care orphan nodes

Super fast !

* UFFS only read a few spares (normally one or two) from each block rather then all spares !!

UFFS device

Bad blocks

Erased blocks

Dir nodes

File nodes

Data nodes

## UFFS tags

- Page spare/UFFS tags

struct uffs_TagStoreSt {

u32 dirty:1;

u32 valid:1;

u32 type:2;

u32 block_ts:2;

u32 data_len:12;

u32 serial:14;

u32 parent:10;

u32 page_id:6;

u32 reserved:4;

u32 tag_ecc:12;

};

sizeof(struct uffs_TagStoreSt) = 8, small enough to store on spare area

* Note: if using RS-ECC on small page MLC, then tag may store on page data area

## UFFS block info cache

- UFFS block info cache

struct uffs_pageSpareSt {

u8 expired:1;

uffs_Tags tag;

};

struct uffs_blockInfoSt {

struct uffs_blockInfoSt *next;

struct uffs_blockInfoSt *prev;

u16 blockNum;

struct uffs_pageSpareSt *spares;

int expiredCount;

int refCount;

};

uffs_config.h:

MAX_CACHED_BLOCK_INFO(5 ~10)

Memory: 40 bytes for each cached info

## UFFS page buffer

- UFFS page buffer

struct uffs_BufSt{

struct uffs_BufSt *next;

struct uffs_BufSt *prev;

struct uffs_BufSt *nextDirty;

struct uffs_BufSt *prevDirty;

u8 type;

u8 ext_mark;

u16 parent;

u16 serial;

u16 pageID;

u16 mark;

u16 refCount;

u16 dataLen;

u8 * data;

u8 * header;

};

uffs_config.h:

MAX_PAGE_BUFFERS (10 ~ 40)

Memory: (40 + page_size) each buffer

## UFFS page status

Valid page

Discarded page

Free page

- Free page: no page id assigned yet. Free pages are always on the bottom.
- Valid page: the page with a id and have max page offset
- Discarded page: the page with page id, there are one or more pages have the same id and bigger page offset.
- Unknown status: interrupted while writing a page.

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
## UFFS block status

Valid page

Discarded page

Free page

- Bad block
- Free/Erased block
- Non-full loaded block (have one or more free pages)
- Full loaded block (no free page, page id = physical page offset)

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
Bad block

Free block

Non-full loaded block

13

14

15

Full loaded block

## UFFS block recover(1)

- Block recover happens when:
  - No more free pages available inside the block and
  - Data were modified and/or
  - Flush the buffer
- Block recover steps:
  - (1)Get a free/erased block from erased block list
  - (2)Copy pages from old block, write to new block with newer timestamps
  - (3)Erase the old block
  - (4)Put the old block to erased block list
  - Note: (1) and (4) are operating in memory. (2) and (3) identified by timestamps, all steps allow to be interrupted at any time ! (Guaranteed integrity across unexpected power losses)

## UFFS block recover(2)

- No block recover if there are enough free pages

Block 1234

0

Block 1234

0

1

1

Since there are free pages, no block recover happens.

Mark old page as discarded, and generate a new page.

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
Valid page

Discarded page

Free page

## UFFS block recover(3)

- Recover a non-full loaded block

Block 1234

0

Block 5678

0

1

No more free page available in this block, modify any pages from 0-7, or add a new page 8, will cause block recovering.

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
Valid page

Discarded page

Free page

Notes: See uffs_buf.c: static URET _BufFlush_Exist_With_BlockCover ( uffs_Device *dev, TreeNode *node, uffs_blockInfo *bc )

## UFFS block recover(4)

- Recover a full-loaded block

Block 1234

0

Block 5678

0

Modify any page of full-loaded block will cause block recovering.

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
Valid page

Discarded page

Free page

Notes: See uffs_buf.c: static URET _BufFlush_Exist_With_BlockCover ( uffs_Device *dev, TreeNode *node, uffs_blockInfo *bc )

## UFFS Page layout

Status byte

mini-

header

Seal byte

ECC

DATA

Tag

- Mini-header (4B) and DATA on page data area, Tag, ECC and 'seal byte' on spare area
- In some case (for example, when using hardware RS-ECC on small page MLC), you can treat the whole NAND page as one body, blur the page data and spare area boundary.
- The 'status byte': this is the first byte of mini-header. If status byte is not 0xFF – this page is “dirty”, page program already started.
- The 'seal byte': this is the last byte of spare data. If seal byte is not 0xFF – this page is “sealed”, all data and tag/ECC have been programmed successfully.

## UFFS bad block management

- Bad block discover when mounting UFFS
- Bad block discover when read/write/erase
  - Try ECC error correct
  - If ECC fail, there is no way get valid data
  - Do not process bad block immediately, leave it at the end of Read/Write operation.
  - Only handle one bad block during the one read/write operation.
- Check bad block when formating UFFS

## How ECC works ? (1)

- XOR: A ^ B = C
  - 0 ^ 0 = 0
  - 1 ^ 0 = 1
  - 0 ^ 1 = 1
  - 1 ^ 1 = 0
- Knowing any two of A, B and C, will know the rest one.
- UFFS ECC: 3 bytes ECC for 256 bytes data
  - 256 Bytes ==> 2048 Bits ===> 256(row) X 8(col)

## How ECC works ? (2)

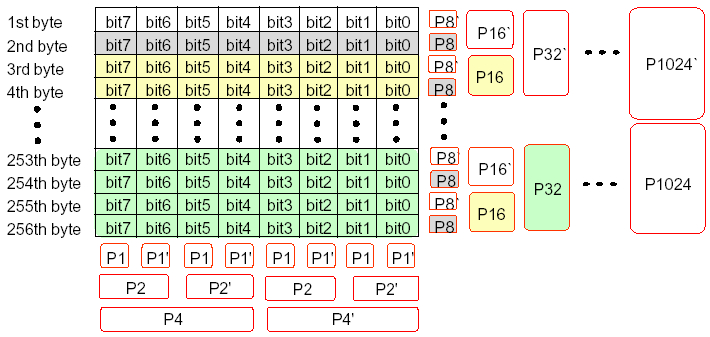
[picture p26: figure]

## UFFS Flash Interface

- struct uffs_FlashOpsSt:
  - Use hardware ECC, or leave it to UFFS
  - Allow driver do the spare layout, or leave it to UFFS
  - Return flash operation status
  - Sequential page programing. No partial page programing.

## UFFS Limitations

- Only one file/dir on one block
- Dynamic wear-leveling, Static wear-leveling is not implemented.

## The next: UFFS2 ?

- Smaller Tree Node (12 bytes), save 25% RAM
- Use NAND block as buffers
- Multiple files/dirs on one block
- Support 8K, 16K page size
- Static wear-leveling
- Symbol link, FIFO file ?
- NOR flash support ? Maybe ...

## The End

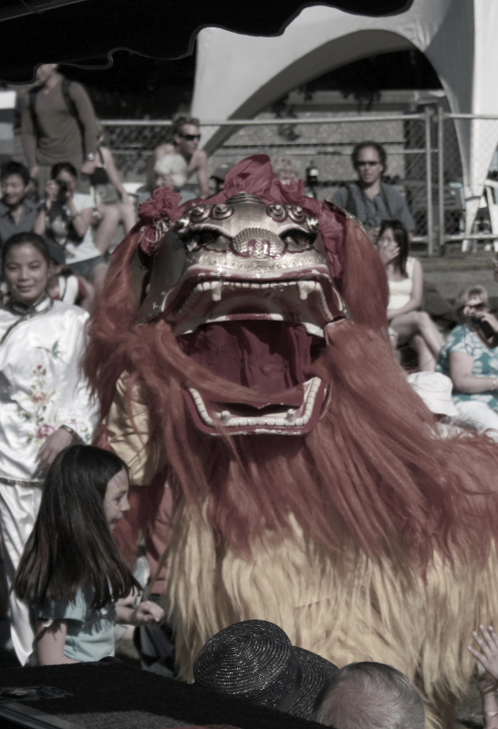
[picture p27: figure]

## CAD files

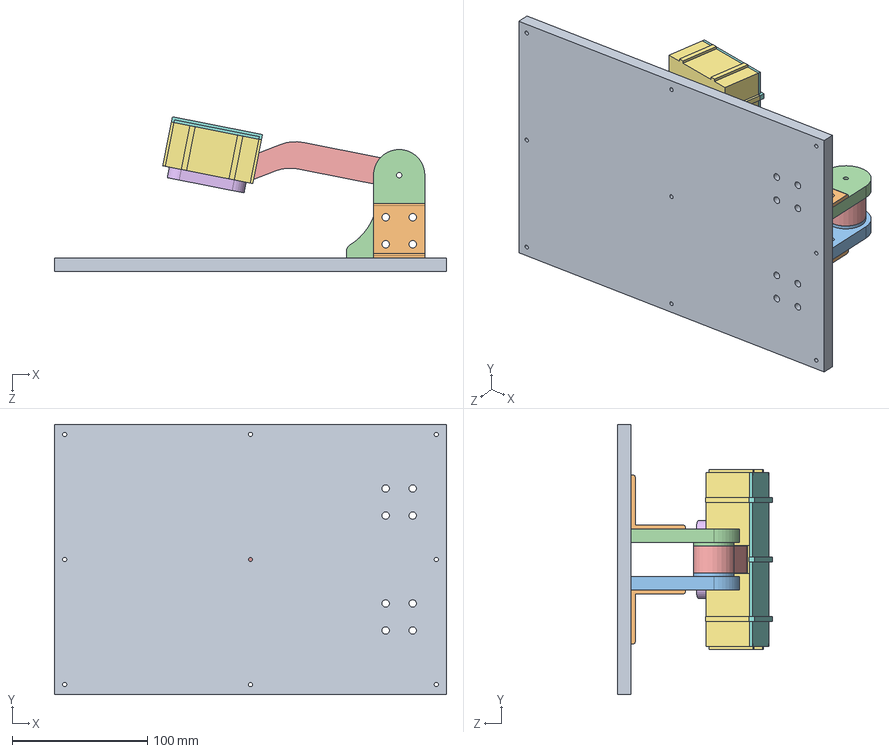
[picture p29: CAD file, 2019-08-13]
mechanical/装配体1.SLDASM
290.0 x 200.0 x 114.3 mm
底板
角铝连接件----8孔 x 2
支座1
支座2
力臂2
极座2
箱体
箱盖

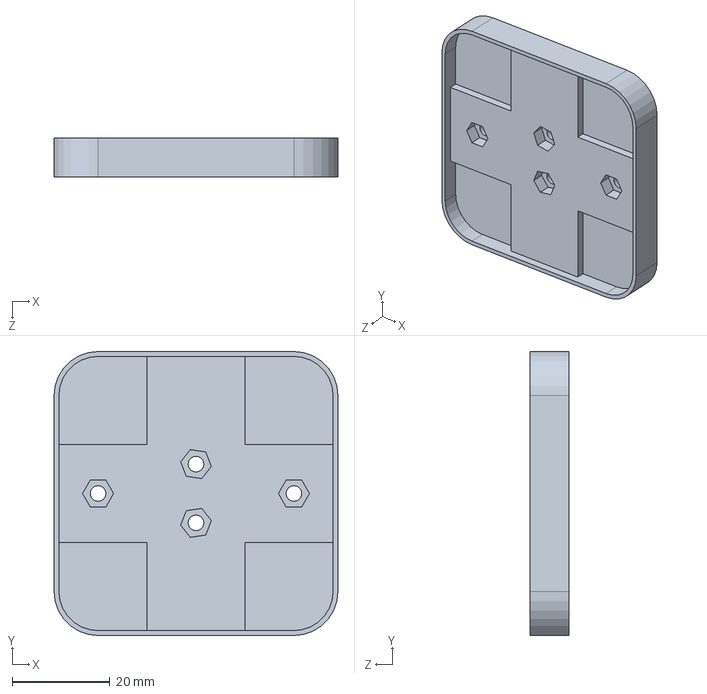
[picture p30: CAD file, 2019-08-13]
mechanical/极座.SLDPRT
58.0 x 58.0 x 8.00 mm

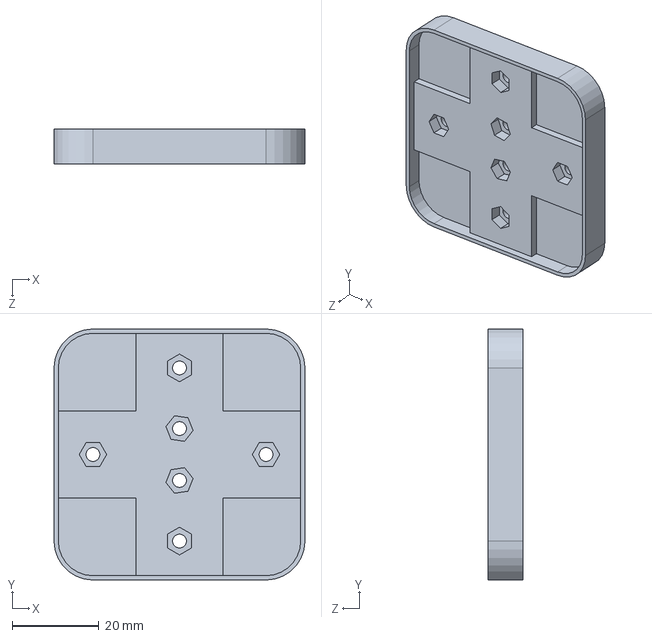
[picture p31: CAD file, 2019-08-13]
mechanical/极座2.SLDPRT
58.0 x 58.0 x 8.00 mm

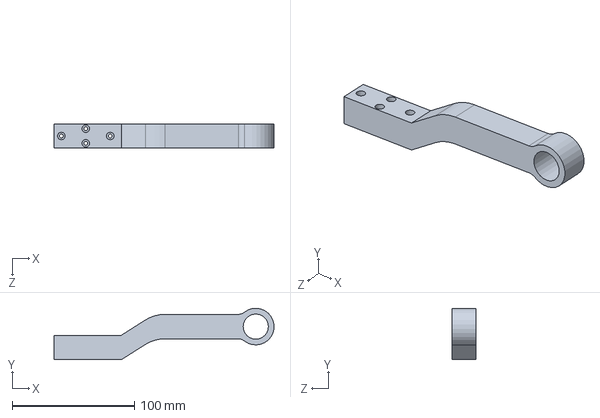
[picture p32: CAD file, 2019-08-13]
mechanical/力臂2.SLDPRT
179.9 x 42.1 x 20.0 mm

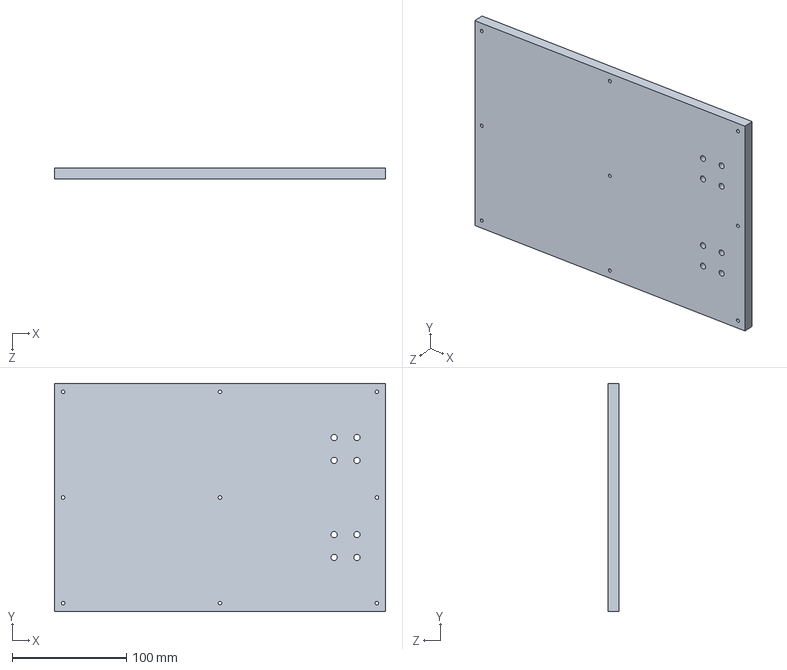
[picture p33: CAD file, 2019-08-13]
mechanical/底板.SLDPRT
290.0 x 200.0 x 10.0 mm

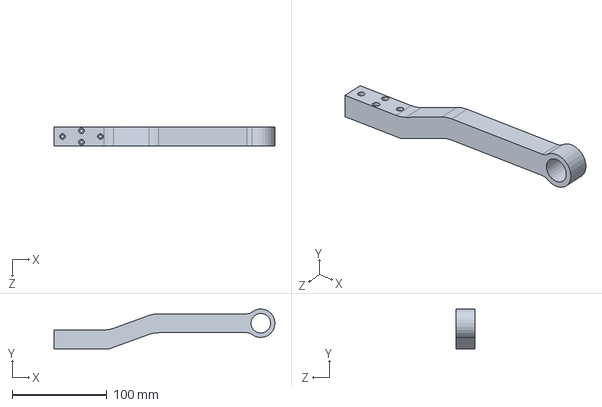
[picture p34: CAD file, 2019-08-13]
mechanical/力臂.SLDPRT
233.0 x 42.1 x 20.0 mm

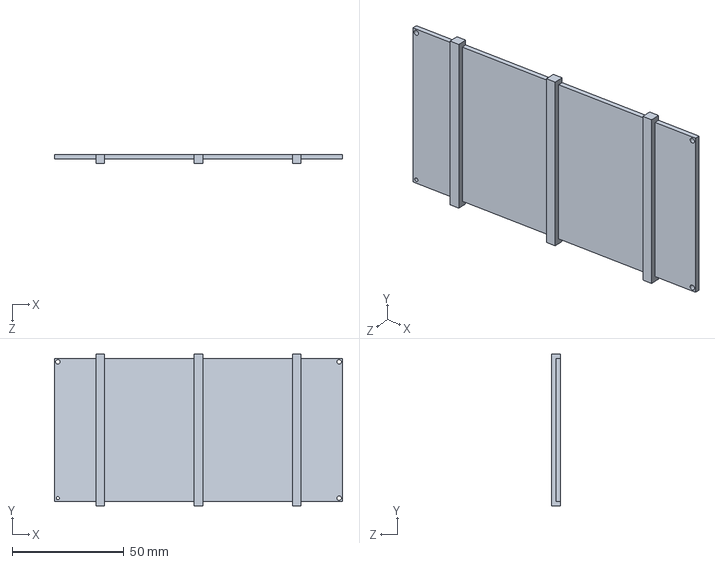
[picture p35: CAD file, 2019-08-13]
mechanical/箱盖.SLDPRT
129.0 x 68.0 x 4.00 mm

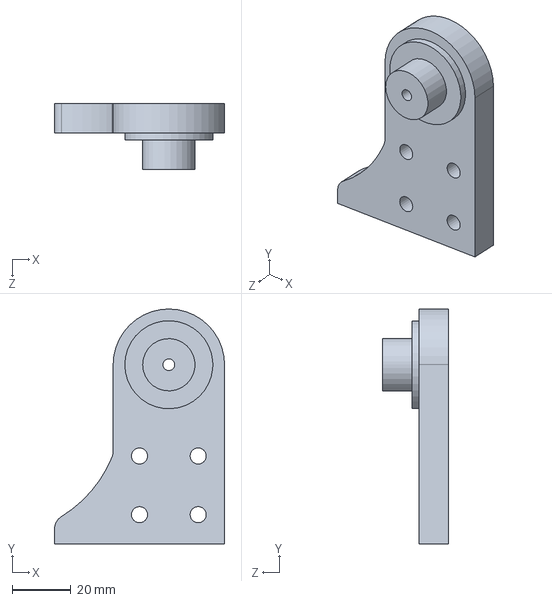
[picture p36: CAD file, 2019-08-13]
mechanical/支座1.SLDPRT
58.0 x 80.1 x 22.5 mm

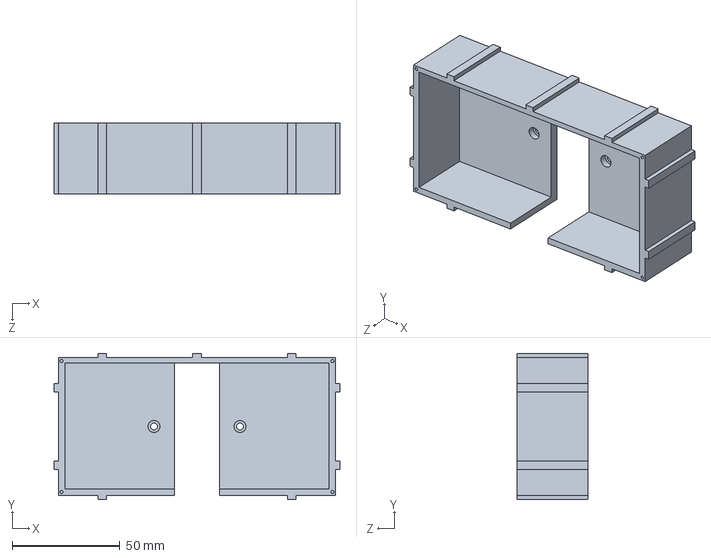
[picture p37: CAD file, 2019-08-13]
mechanical/箱体.SLDPRT
133.0 x 68.0 x 33.0 mm

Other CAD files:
mechanical/支座2.SLDPRT
mechanical/力臂.STL
mechanical/力臂2.STL
mechanical/支座1.STL
mechanical/支座2.STL
mechanical/极座.STL
mechanical/极座2.STL
mechanical/箱体.STL
mechanical/箱盖.STL

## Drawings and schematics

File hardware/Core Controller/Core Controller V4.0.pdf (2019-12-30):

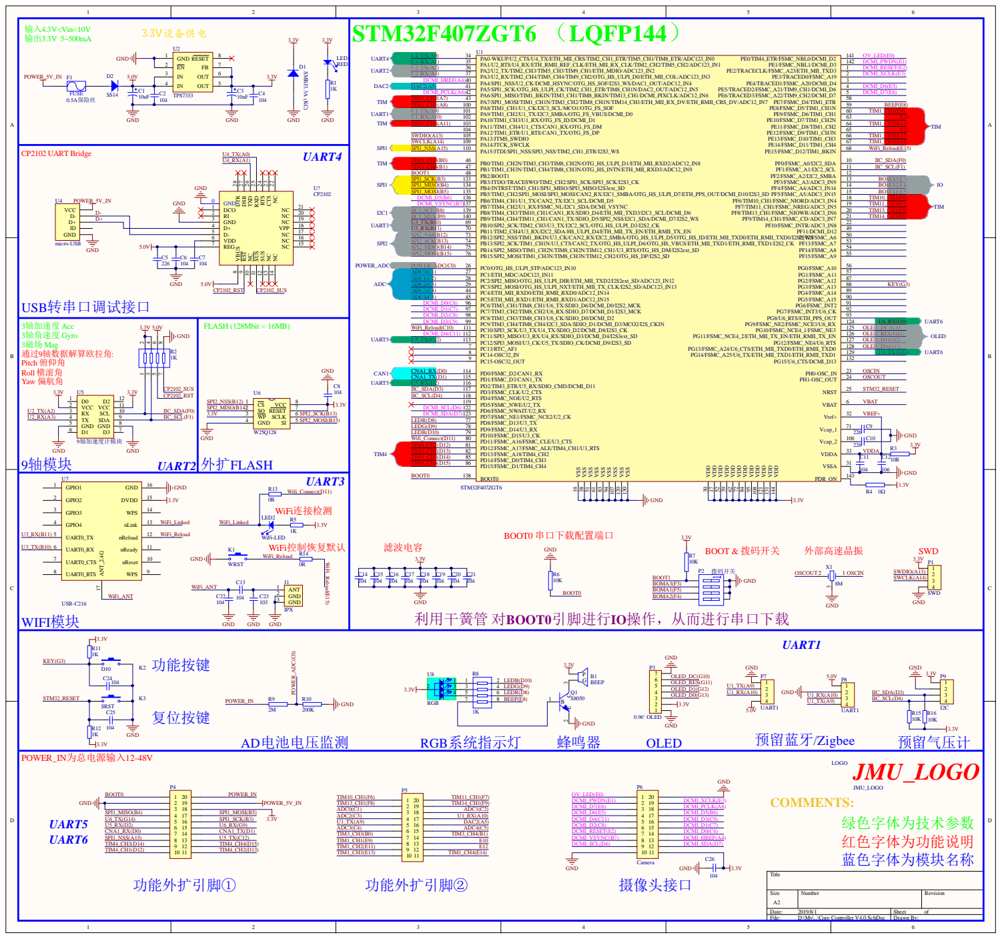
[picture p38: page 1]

输入4.3V<Vin<10V 3.3V设备供电 输出3.3V 5~500mA 3.3V 3.3V U2 | STM32F407ZGT6 （LQFP144） U1

Size A2 | Number | Revision

Date: 2019/8/1 | Sheet of
File: D:\My\..\Core Controller V4.0.SchDoc | Drawn By:

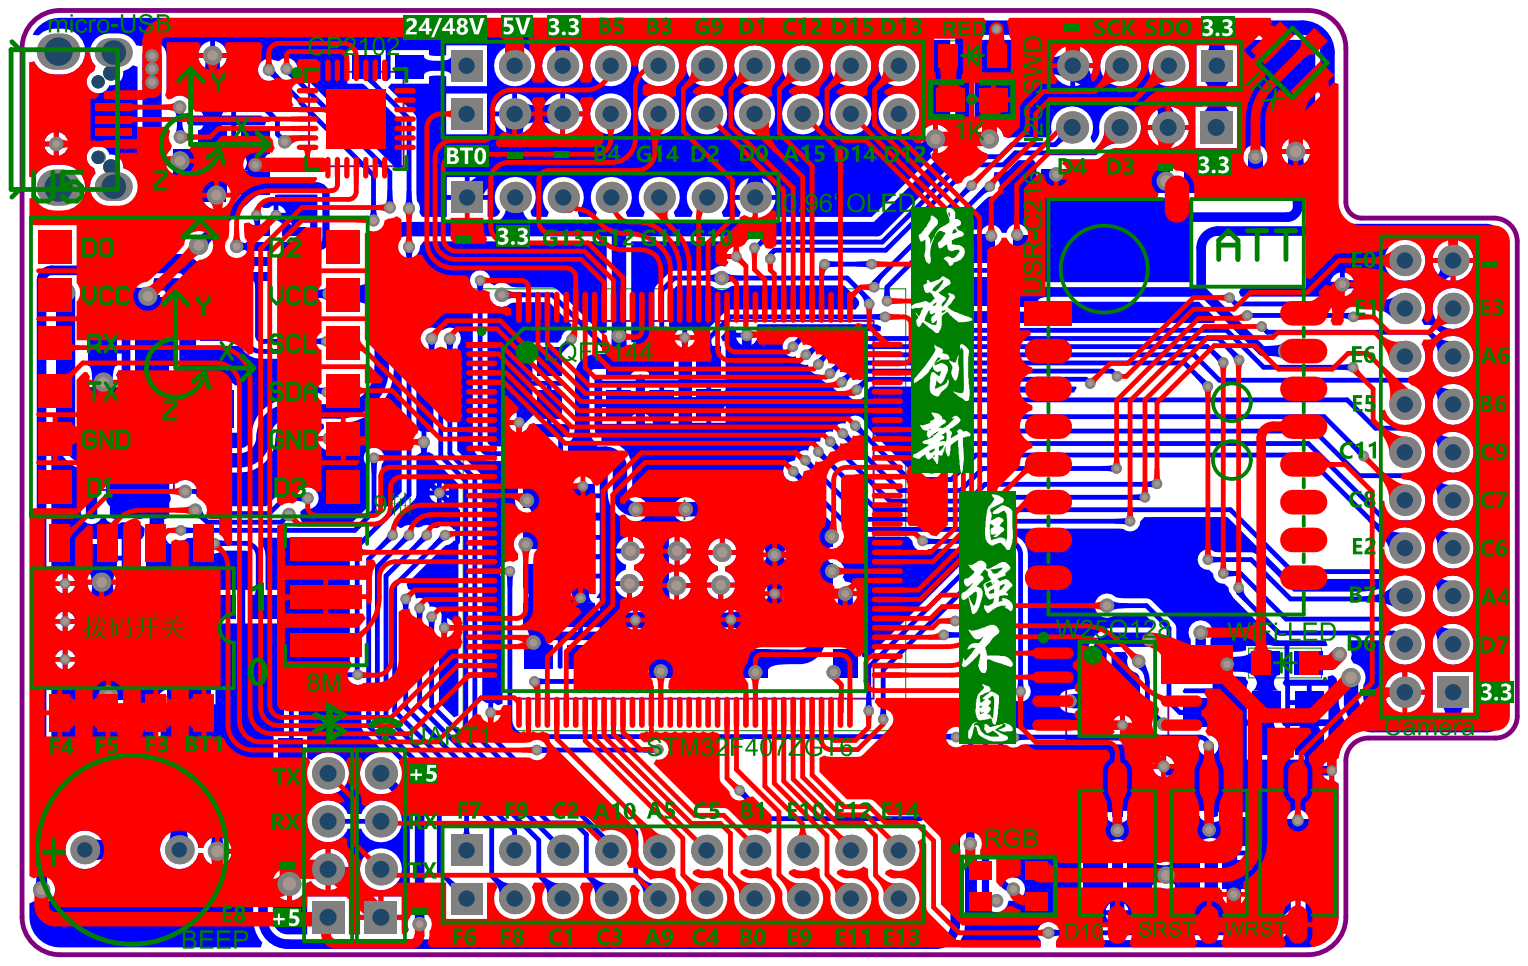
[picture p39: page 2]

Comment | Description | Designator | Footprint | LibRef | Quantity
BEEP | | B1 | BUZZER | BEEP | 1
10uF | 极性贴片电容 | C1, C3 | TAJ-A | Pol Cap | 2
104 | 无极贴片电容, 无极贴片 电容, 无极贴片电容, 无 极贴片电容, 无极贴片电 容, [NoValue], 无极贴片 电容, [NoValue], [NoValue], [NoValue], [NoValue], [NoValue], [NoValue], [NoValue], [NoValue], 无极贴片电 容, [NoValue], [NoValue], 无极贴片电 容 | C2, C4, C6, C7, C8, C11, C13, C14, C15, C16, C17, C18, C19, C20, C21, C22, C24, C25, C26 | 0805C | Cap1, Cap1, Cap1, Cap1, Cap1, C1, Cap1, C1, C1, C1, C1, C1, C1, C1, C1, Cap1, C1, C1, Cap1 | 19
226 | 无极贴片电容, [NoValue], [NoValue] | C5, C9, C10 | 0805C | Cap1, C1, C1 | 3
106 | | C12 | 0805C | C1 | 1
103 | 无极贴片电容 | C23 | 0805C | Cap1 | 1
SMBJ3.3A (KC) | 二极管 | D1 | SMBJ | Diode | 1
SS14 | 二极管 | D2 | SMA/DO-214AC | Diode | 1
0.5A保险丝 | 保险丝 | F1 | 1206R | Fuse | 1
IPX | | J1 | IPX天线底座 | IPX天线座 | 1
WRST | 轻触开关 | K1 | 贴片按键 | 轻触按键 | 1
D10 | | K2 | 贴片按键 | Key(两脚贴片) | 1
SRST | | K3 | 贴片按键 | Key(两脚贴片) | 1
RED | 发光二极管 | LED1 | 0805LED(RED) | LED | 1
WiFi-LED | 发光二极管 | LED2 | 0805LED(GREEN) | LED | 1
JMU_LOGO | LOGO | LOGO | JMU_LOGO(1.35cm) | JMU_LOGO | 1
SWD | 排针 | P1 | Header 4 | Header 4 | 1
拨码开关 | 4位拨码开关 | P2 | 拨码开关(4位贴片) | 拨码开关4 | 1
0.96‘ OLED | 排针 | P3 | Header 7 | Header 7 | 1
| | P4, P5 | Header 10X2 | Header 10X2 | 2
Camera | | P6 | Header 10X2 | Header 10X2 | 1
UART1 | 排针 | P7, P8 | Header 4(排母) | Header 4 | 2
I2C | 排针 | P9 | Header 4(排母) | Header 4 | 1
S8050 | NPN三极管 | Q1 | SOT-23 | NPN | 1
1K | [NoValue], 电阻, 电阻, 电阻 | R1, R5, R11, R12 | 0805R | R1, Res, Res, Res | 4
1K | 排阻 | R2, R8 | 排阻(4位贴片) | Res-4 | 2
10R | | R3 | 0805R | R1 | 1
0Ω | | R4 | 0805R | R1 | 1
10K | [NoValue], [NoValue], 电阻, 电阻 | R6, R7, R15, R16 | 0805R | R1, R1, Res, Res | 4
2M | | R9 | 0805R | R1 | 1
200K | | R10 | 0805R | R1 | 1
0R | 电阻 | R13, R14 | 0805R | Res | 2
STM32F407ZGT6 | | U1 | LQFP-144 | STM32F407ZET6 | 1
TPS7333 | 3.3V电源芯片 | U2 | SOP-8 | TPS7333 | 1
micro-USB | USB接口 | U4 | Micro-USB (兼容牛角) | micro-USB | 1
9轴加速度计模块 | | U5 | 9轴加速度计 | 9轴加速度计 | 1
W25Q128 | FLASH芯片 | U6 | SOW-8 | W25Q128 | 1
USR-C216 | | U7 | USR-C216 | USR-C216 | 1
RGB | | U8 | RGB-3528 | RGB | 1
CP2102 | USB转串口芯片 | U? | QFN-28 | CP2102 | 1
8M | | X1 | 三脚贴片8M晶振 | XTAL三脚贴片晶振 | 1

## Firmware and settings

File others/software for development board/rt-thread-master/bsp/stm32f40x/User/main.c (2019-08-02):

/******************************************************************************
* Copyright 2019-2020 JMU Electronic Technology Association / zengwangfa@outlook.com
*
* ProjectName: Underwater Vehicle Control
* Desc: 			 Peripherals control
*
* Author:  Dwfish
* Date: 	 2019-02-06
*
* -----------------------------------------------------------------
 * Change Logs:
 * Date           Author       Notes
 * 2019-02-06     Dwfish       Creat LED / KEY / Buzzer /PWM /ADC Thread.
 * 2019-02-07     Dwfish       Creat OLED Display Thread.
 * 2019-02-09     Dwfish       Creat Get_Gyroscope Thread. 
 * 2019-02-11     Dwfish       Creat some MSHs (get methods) & Improved OLED display methods. 
 * 2019-02-13     Dwfish       Creat Can change Servo Motor Mid-Value MSH. 
 * 2019-02-16     Dwfish       Creat System self-check methods[events]. 
 * 2019-02-16     Dwfish       Add W25Q128 FLASH To Save Important Parameters.
 * 2019-02-16     Dwfish       Creat OLED Electronic compass.
 * 2019-02-19     Dwfish       Add VACN & ANO host computer debug.
 * 2019-02-20     Dwfish       Add Easylog & Easyflash & <update> msh.
 * 2019-03-24     Dwfish       Add Cpuusage.
 * 2019-04-19     Dwfish       Add Focus Camera ControlCmd.
 * 2019-07-01     Dwfish       Add Control Method.
	
	Bugs:
 * 2019-04-29     BUG:IAP Download dispaly success,but Download fail.

*
******************************************************************************/
#define LOG_TAG    "main"


#include <rtthread.h>
#include "DataType.h" //自定义数据类型 头文件【重要】

/* 最重要定义 直接从设定好的模式(Flash中读取)*/
volatile uint8 VehicleMode = FOUR_AXIS;   //【FOUR_AXIS】 or 【SIX_AXIS】
volatile uint8 WorkMode    = WORK;        //【WORK】 or 【DEBUG】
//volatile 的作用 是作为指令关键字，确保本条指令不会因编译器的优化而省略，且要求每次直接在其内存中读值。
/**
 * @addtogroup STM32
 */

/* 打印相关日志信息 */
int main(void)
{
    /* user app entry. */

//		rt_kprintf("* >>>>>>>>>>>>>>>>>>>>>>>>>>>>>>>>>>>>>>>>>>>>>>>>>>>>>>>>>>>>>>>>>>\n");	
//		rt_kprintf("* ProjectName: Underwater Vehicle Control	\n");
//		rt_kprintf("* Desc:    Peripherals control	\n");
//		rt_kprintf("*	\n");
//		rt_kprintf("* Author:  Dwfish	\n");
//		rt_kprintf("* Date:	   2019-02-06	\n");
//		rt_kprintf("*	\n");
//		rt_kprintf("* -----------------------------------------------------------------\n");
//		rt_kprintf("* Change Logs:\n");
//		rt_kprintf("* Date           Author       Notes\n");
//	
//		rt_kprintf("* 2019-02-06     Dwfish       Creat LED / KEY / Buzzer /PWM /ADC Thread.\n");
//		rt_kprintf("* 2019-02-07     Dwfish       Creat OLED Thread\n"); 
//		rt_kprintf("* 2019-02-09     Dwfish       Creat Get_Gyroscope Thread.\n");
//	
//		rt_kprintf("* 2019-02-11     Dwfish       Creat MSHs (some get methods) && Improved OLED Display. \n");
//		rt_kprintf("* 2019-02-13     Dwfish       Creat Can change Servo Motor Mid-Value MSH-methods.  \n");
//		rt_kprintf("* 2019-02-16     Dwfish       Creat System self-check methods [ Events ].\n");
//		rt_kprintf("* 2019-02-16     Dwfish       Add W25Q128 FLASH To Save Important Parameters.\n");
//		rt_kprintf("* 2019-02-16     Dwfish       Creat OLED Electronic compass.\n");
//		rt_kprintf("* 2019-02-19     Dwfish       Add VACN host computer debug.\n");
//		rt_kprintf("* 2019-02-20     Dwfish       Add Easylog & Easyflash & <update> msh.\n");

//		rt_kprintf("* <<<<<<<<<<<<<<<<<<<<<<<<<<<<<<<<<<<<<<<<<<<<<<<<<<<<<<<<<<<<<<<<<\n");	 
		//print_time();  //打印参考时间戳
		
		return 0;
}

/*
0.[A]：断言(Assert)
1.[E]：错误(Error)
2.[W]：警告(Warn)
3.[I]：信息(Info)
4.[D]：调试(Debug)
5.[V]：详细(Verbose)
*/

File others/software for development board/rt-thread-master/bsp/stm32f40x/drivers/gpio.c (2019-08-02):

/*
 * Copyright (c) 2006-2018, RT-Thread Development Team
 *
 * SPDX-License-Identifier: Apache-2.0
 *
 * Change Logs:
 * Date           Author            Notes
 * 2017-03-24     armink            the first version
 */

#include <rthw.h>
#include <rtdevice.h>
#include <board.h>

#ifdef RT_USING_PIN

#define STM32_PIN_NUMBERS 144 //[48, 64, 100, 144 ]

#define __STM32_PIN(index, rcc, gpio, gpio_index) { 0, RCC_##rcc##Periph_GPIO##gpio, GPIO##gpio, GPIO_Pin_##gpio_index}
#define __STM32_PIN_DEFAULT {-1, 0, 0, 0}

#define ITEM_NUM(items) sizeof(items)/sizeof(items[0])

/* STM32 GPIO driver */
struct pin_index
{
    int index;
    uint32_t rcc;
    GPIO_TypeDef *gpio;
    uint32_t pin;
};

/* STM32 GPIO irq information */
struct pin_irq
{
    /* EXTI port source gpiox, such as EXTI_PortSourceGPIOA */
    rt_uint8_t port_source;
    /* EXTI pin sources, such as EXTI_PinSource0 */
    rt_uint8_t pin_source;
    /* NVIC IRQ EXTI channel, such as EXTI0_IRQn */
    enum IRQn irq_exti_channel;
    /* EXTI line, such as EXTI_Line0 */
    rt_uint32_t exti_line;
};

static const struct pin_index pins[] =
{
#if (STM32_PIN_NUMBERS == 48)
    __STM32_PIN_DEFAULT,
    __STM32_PIN_DEFAULT,
    __STM32_PIN(2, AHB1, C, 13),
    __STM32_PIN(3, AHB1, C, 14),
    __STM32_PIN(4, AHB1, C, 15),
    __STM32_PIN_DEFAULT,
    __STM32_PIN_DEFAULT,
    __STM32_PIN_DEFAULT,
    __STM32_PIN_DEFAULT,
    __STM32_PIN_DEFAULT,
    __STM32_PIN(10, AHB1, A, 0),
    __STM32_PIN(11, AHB1, A, 1),
    __STM32_PIN(12, AHB1, A, 2),
    __STM32_PIN(13, AHB1, A, 3),
    __STM32_PIN(14, AHB1, A, 4),
    __STM32_PIN(15, AHB1, A, 5),
    __STM32_PIN(16, AHB1, A, 6),
    __STM32_PIN(17, AHB1, A, 7),
    __STM32_PIN(18, AHB1, B, 0),
    __STM32_PIN(19, AHB1, B, 1),
    __STM32_PIN(20, AHB1, B, 2),
    __STM32_PIN(21, AHB1, B, 10),
    __STM32_PIN(22, AHB1, B, 11),
    __STM32_PIN_DEFAULT,
    __STM32_PIN_DEFAULT,
    __STM32_PIN(25, AHB1, B, 12),
    __STM32_PIN(26, AHB1, B, 13),
    __STM32_PIN(27, AHB1, B, 14),
    __STM32_PIN(28, AHB1, B, 15),
    __STM32_PIN(29, AHB1, A, 8),
    __STM32_PIN(30, AHB1, A, 9),
    __STM32_PIN(31, AHB1, A, 10),
    __STM32_PIN(32, AHB1, A, 11),
    __STM32_PIN(33, AHB1, A, 12),
    __STM32_PIN(34, AHB1, A, 13),
    __STM32_PIN_DEFAULT,
    __STM32_PIN_DEFAULT,
    __STM32_PIN(37, AHB1, A, 14),
    __STM32_PIN(38, AHB1, A, 15),
    __STM32_PIN(39, AHB1, B, 3),
    __STM32_PIN(40, AHB1, B, 4),
    __STM32_PIN(41, AHB1, B, 5),
    __STM32_PIN(42, AHB1, B, 6),
    __STM32_PIN(43, AHB1, B, 7),
    __STM32_PIN_DEFAULT,
    __STM32_PIN(45, AHB1, B, 8),
    __STM32_PIN(46, AHB1, B, 9),
    __STM32_PIN_DEFAULT,
    __STM32_PIN_DEFAULT,
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

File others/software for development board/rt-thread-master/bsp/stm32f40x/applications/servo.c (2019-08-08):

/*
 * servo.c
 *
 *  Created on: 2019年3月30日
 *      Author: zengwangfa
 *      Notes:  舵机设备
 */
#define  LOG_TAG    "servo"
#include <stdio.h>
#include <stdlib.h>
#include <rtthread.h>
#include <elog.h>

#include "sys.h"

#include "DataType.h"
#include "Control.h"
#include "ioDevices.h"
#include "servo.h"
#include "propeller.h"
#include "flash.h"
#include "ret_data.h"
#include "rc_data.h"
#include "focus.h"
#include "DeviceThread.h"
#include "PID.h"
/*---------------------- Constant / Macro Definitions -----------------------*/

#define RoboticArm_MedValue  1500
#define YunTai_MedValue  		 2000

/*----------------------- Variable Declarations -----------------------------*/

ServoType RoboticArm = {
		 .MaxValue = 2000, 		//机械臂 正向最大值
		 .MinValue = 1000,	  //机械臂 反向
		 .MedValue = 1500,
	   .Speed  = 5//机械臂当前值
};  //机械臂
ServoType  YunTai = {
		 .MaxValue = 1700, 		// 正向最大值
		 .MinValue = 1100,	  // 反向
		 .MedValue = 1400,
	   .Speed  = 10//云台转动速度
};      //云台


uint16 propeller_power = 1500;



/*----------------------- Function Implement --------------------------------*/


/*******************************************
* 函 数 名：Servo_Output_Limit
* 功    能：舵机输出限制
* 输入参数：输入值：舵机结构体地址 
* 返 回 值：None
* 注    意：
********************************************/
void Servo_Output_Limit(ServoType *Servo)
{
		Servo->CurrentValue = Servo->CurrentValue > Servo->MaxValue ? Servo->MaxValue : Servo->CurrentValue ;//正向限幅
		Servo->CurrentValue = Servo->CurrentValue < Servo->MinValue ? Servo->MinValue : Servo->CurrentValue ;//反向限幅
	
}







/*  小车舵机 控制*/
void Servo_Dir_Control(short offest) //PWM越大 ,往右
{

	
		//YunTai.CurrentValue = YunTai.MedValue + (offest);
	
		Servo_Output_Limit(&YunTai); //限幅
		TIM4_PWM_CH4_D15(YunTai.CurrentValue);  //输出

}


/* 云台控制 

当前x，期望x;当前y，期望y
*/
void yuntai_pid_control(float present_x,float expect_x,float persent_y,float expect_y) //
{

    /* 航向角 为 X*/
		Total_Controller.Yaw_Angle_Control.FeedBack = present_x;  //当前深度反馈
		Total_Controller.Yaw_Angle_Control.Expect = expect_x ; //期望深度由遥控器给定	
	
		/* 俯仰角 为 Y*/
		Total_Controller.Pitch_Angle_Control.FeedBack = persent_y;  //当前深度反馈
		Total_Controller.Pitch_Angle_Control.Expect = expect_y ; //期望深度由遥控器给定
	
	
		PID_Control(&Total_Controller.Pitch_Angle_Control);//高度位置控制器
		PID_Control(&Total_Controller.Yaw_Angle_Control);//高度位置控制器
	
}

/*【推进器】 修改 【正向最大值】MSH方法 */
static int pitch_yuntai(int argc, char **argv)
{

    int result = 0;
    if (argc != 2){
        log_e("Error! Proper Usage: Propoller_Test <0~100>");
				result = -RT_ERROR;
        goto _exit;
    }
		if(atoi(argv[1]) <= 200000){

				PropellerPower.rightMiddle = atoi(argv[1]);

				log_i("Current propeller power:  %d",atoi(argv[1]) );
		}
		
		else {
				log_e("Error! The value is out of range!");
		}
_exit:
    return result;
}
MSH_CMD_EXPORT(pitch_yuntai,ag: two_axis_yuntai 1000 1000);



/*【推进器】 修改 【正向最大值】MSH方法 */
static int yaw_yuntai(int argc, char **argv)
{

    int result = 0;
    if (argc != 2){
        log_e("Error! Proper Usage: Propoller_Test <0~100>");
				result = -RT_ERROR;
        goto _exit;
    }
		if(atoi(argv[1]) <= 200000){

				PropellerPower.leftMiddle = atoi(argv[1]);

				log_i("Current propeller power:  %d",atoi(argv[1]) );
		}
		
		else {
				log_e("Error! The value is out of range!");
		}
_exit:
    return result;
}
MSH_CMD_EXPORT(yaw_yuntai,ag: two_axis_yuntai 1000 1000);


/**
  * @brief  RoboticArm_Control(机械臂控制)
  * @param  控制指令 0x00：不动作  0x01：张开  0x02：关闭
  * @retval None
  * @notice 
  */
void RoboticArm_Control(uint8 *action)
{
		switch(*action)
		{
				case 0x01:RoboticArm.CurrentValue += RoboticArm.Speed;
									if(RoboticArm.CurrentValue >= RoboticArm.MaxValue){device_hint_flag |= 0x01;}//机械臂到头标志
									else {device_hint_flag &= 0xFE;}; //清除机械臂到头标志

									break;
				case 0x02:RoboticArm.CurrentValue -= RoboticArm.Speed;
									if(RoboticArm.CurrentValue <= RoboticArm.MinValue){device_hint_flag |= 0x01;}//机械臂到头标志
									else {device_hint_flag &= 0xFE;}; //清除机械臂到头标志

									break;
				default:break;
		}
		Servo_Output_Limit(&RoboticArm);//机械臂舵机限幅
		TIM4_PWM_CH3_D14(RoboticArm.CurrentValue);
		*action = 0x00; //清除控制字
}




/**
  * @brief  YunTai_Control(云台控制)
  * @param  控制指令 0x00：不动作  0x01：向上  0x02：向下
  * @retval None
  * @notice 
  */

void YunTai_Control(uint8 *action)
{
		switch(*action)
		{
				case 0x01:YunTai.CurrentValue += YunTai.Speed;  //向上
						if(YunTai.CurrentValue <= YunTai.MaxValue){device_hint_flag |= 0x02;}//云台到头标志
						else {device_hint_flag &= 0xFD;}; //清除云台到头标志

						break;  
						
				case 0x02:YunTai.CurrentValue -= YunTai.Speed; //向下
						if(YunTai.CurrentValue >= YunTai.MinValue){device_hint_flag |= 0x02;}//云台到头标志
						else {device_hint_flag &= 0xFD;}; //清除云台到头标志

						break;  

				case 0x03:YunTai.CurrentValue = YunTai.MedValue;break;   //归中
				default: break;
		}
		Servo_Output_Limit(&YunTai);
		//TIM4_PWM_CH4_D15(YunTai.CurrentValue); 
		*action = 0x00; //清除控制字
}







//short _test_value = 0;
///*【吸取器】 修改 【测试】 MSH方法 */
//static int xiquqi_value_set(int argc, char **argv)
//{
//    int result = 0;
//    if (argc != 2){
//        log_e("Error! Proper Usage: robotic_arm_currentValue_set <0~3000>");
//				result = -RT_ERROR;
//        goto _exit;
//    }

//		if(atoi(argv[1]) <= 3000 ){		
//				_test_value = atoi(argv[1]);
//				log_i(" Value:  %d",_test_value);
//				TIM3_PWM_CH3_B0(_test_value);
//		}
//		else {
//				log_e("Error! The value is out of range!");
//		}
//_exit:
//    return result;
//}
//MSH_CMD_EXPORT(xiquqi_value_set,ag: xiquqi_value_set <0~3000>);





///*【云台】舵机 修改 【当前】 MSH方法 */
//static int robotic_arm_currentValue_set(int argc, char **argv)
//{
//    int result = 0;
//    if (argc != 2){
//        log_e("Error! Proper Usage: robotic_arm_currentValue_set <0~3000>");
//				result = -RT_ERROR;
//        goto _exit;
//    }

//		if(atoi(argv[1]) <= 3000 ){		
//				RoboticArm.CurrentValue = atoi(argv[1]);
//				log_i(" Value:  %d",RoboticArm.CurrentValue);
//				TIM4_PWM_CH3_D14(RoboticArm.CurrentValue);


//		}
//		else {
//				log_e("Error! The value is out of range!");
//		}
//_exit:
//    return result;
//}
//MSH_CMD_EXPORT(robotic_arm_currentValue_set,ag: robotic_arm_currentValue_set <0~3000>);





///*【机械臂】舵机 修改 速度值 */
//static int robotic_arm_speed_set(int argc, char **argv)
//{
//    int result = 0;
//    if (argc != 2){
//        log_e("Error! Proper Usage: RoboticArm_Speed 10");
//				result = -RT_ERROR;
//        goto _exit;
//    }
//		if(atoi(argv[1]) <= 255 && atoi(argv[1]) > 0){
//				RoboticArm.Speed = atoi(argv[1]);
//				Flash_Update();
//				log_i("Write_Successed! RoboticArm.Speed:  %d",RoboticArm.Speed);
//		}
//		
//		else {
//				log_e("Error! The value is out of range!");
//		}
//_exit:
//    return result;
//}
//MSH_CMD_EXPORT(robotic_arm_speed_set,ag: robotic_arm_speed_set 10);
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

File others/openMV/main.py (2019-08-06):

import sensor, image, time, math , pyb ,json,single_blob,find_line,partition_patrol
from pyb import LED,UART,Timer

threshold_index = 1 # 0 for red, 1 for green, 2 for blue


# Color Tracking Thresholds (L Min, L Max, A Min, A Max, B Min, B Max)
thresholds = [(0, 30, 0, 64, -128, 0),
              (79, 100, -37, -2, -4, 24), # 绿色激光
              (50, 77, 16, 65, -19, 31) # 红色激光
              ] # generic_blue_thresholds


sensor.reset() # 传感器复位sensor.set_pixformat(sensor.GRAYSCALE) # use grayscale.
sensor.set_pixformat(sensor.RGB565) # RGB565即一个彩色图像点由RGB三个分量组成，总共占据2Byte，高5位为R分量，中间6位为G分量，低5位为B分量
sensor.set_framesize(sensor.QVGA) # 320*240
sensor.skip_frames(time = 500) # 跳过，等待摄像头稳定
sensor.set_auto_gain(False) # 自动增益在颜色识别中一般关闭，不然会影响阈值
sensor.set_auto_whitebal(False) # 白平衡在颜色识别中一般关闭，不然会影响阈值
clock = time.clock() # 构造时钟对象


uart = UART(3, 115200)
uart.init(115200, bits=8, parity=None, stop=1, timeout_char=1000) # 使用给定参数初始化 timeout_char是以毫秒计的等待字符间的超时时长



class ctrl_info(object):
    WorkMode = 0x01 # 色块检测模式  0x01为固定单颜色识别  0x02为自主学习颜色识别  0x03 巡线
    Threshold_index = 0x00 # 阈值编号

ctrl = ctrl_info() # 定义控制信息类
single_blob.InitSuccess_LED() # 初始化完成 Green LED 快闪2下
'''-----------------------------------------------初始化分割线------------------------------------------------'''


while(True):

    clock.tick() # 追踪时钟
    img = sensor.snapshot() # thresholds为阈值元组0
    if ctrl.WorkMode == 0x01:
        single_blob.single_blob(img,ctrl,thresholds,1,uart)
        single_blob.single_blob(img,ctrl,thresholds,2,uart)
    elif ctrl.WorkMode == 0x02:
        a = 0 # 暂时为空
    elif ctrl.WorkMode == 0x03:
        find_line.find_line(img,ctrl,uart)

    elif ctrl.WorkMode == 0x04:
        partition_patrol.partition_find_line(img,ctrl,uart)

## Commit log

2019-08-02 创建仓库
    [kconfig-language.txt, kconfig.txt]
2019-08-03 【更新】提交 云台基本控制
2019-08-03 【更新】更新云台闭环控制
    [画圆数据测试.xlsx]
2019-08-06 【更新】提交OpenMV处理
2019-08-06 【更新】更新uart发送
2019-08-06 【更新】完善激光追踪 控制
2019-08-07 【更新】完善 FDC2214采集 以及 数据处理
2019-08-07 【更新】更新大致控制 流程
2019-08-07 【更新】提交 FDC2214控制板
    [SV601187A.PcbDoc, SV601187A.SchDoc]
2019-08-07 【更新】提交 HMI串口屏 文件
2019-08-07 【更新】完善HMI 串口屏 功能
2019-08-08 【更新】完善OLED显示 控制
2019-08-08 【更新】
2019-08-08 【提交】提交串口屏V2.0
2019-08-08 【更新】修复了 短路检测
2019-08-08 【更新】初步完成了 智障检测
2019-08-08 【更新】裁剪系统，优化了系统结构，提高运行速度
2019-08-08 【更新】修复了诸多bugs
2019-08-08 【更新】完善了一些标志位
2019-08-09 【更新】提交V4.0 串口屏界面
2019-08-09 【更新】提交 整体控制逻辑switch
2019-08-09 【更新】提交 最小系统板程序
    [kconfig-language.txt, kconfig.txt]
2019-08-09 【更新】完善控制OLED逻辑
2019-08-09 【更新】优化了短路检测
2019-08-10 【提交】提交 扩展功能
2019-08-10 【更新】修复了 开发板 按键检测问题
2019-08-10 【更新】matlab截图
2019-08-10 【更新】提交 V4.0版本，添加 扩展功能
2019-08-11 【整理】提交 HMI V4.0
2019-08-11 【整理】整理代码
2019-08-11 【整理】整理串口屏设计
2019-08-11 【整理】整理了电磁炮代码
    [kconfig-language.txt, kconfig.txt]
2019-08-12 【整理】整理了代码结构，作为总结
2019-08-12 【整理】整理核心代码
2019-08-12 【整理】整理串口屏
2019-08-13 【整理】整理更新机械结构 三维图
    [力臂.SLDPRT, 力臂.STL, 力臂2.SLDPRT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]
2019-08-13 【整理】整理提交
2019-08-13 【整理】后期整理文档
    [以sin画圆.xlsx, 机械臂减震结构数据.xlsx, 电容与纸上数值（洗衣液版本）.xlsx]
2019-08-13 【整理】
2019-08-13 【后期整理】
2019-08-16 【更新】提交测评相关电路仿真
2019-08-22 【整理】提交2019电赛赛题
    [全国竞赛题目清单.xlsx]
2019-09-06 【更新】整理提交
2019-09-12 【更新】整理更新README
2019-09-12 【更新】整理更新说明文档
2019-09-12 【更新】整理README
2019-10-23 【更新】完善文档
2019-10-23 【更新】提交2017综测题目
2019-10-24 【整理】整理更新、完善说明文档、目录结构
2019-10-24 【删除】删除核心板
    [Core Controller V4.0.PrjPcb, Core Controller V4.0.SchDoc]
2019-11-18 【更新】修正说明文档
2019-11-20 【更新】完善说明文档
2019-12-11 【更新】修改说明文档
2019-12-30 【:bugs:】整理更新说明文档、代码、添加注释
2019-12-30 【更新】修改文件名称
2019-12-30 【更新】提交硬件核心控制器原理图
2019-12-30 【更新】:framed_picture:添加相关实物图及测试图
2019-12-30 【更新】:scroll: 完善相关说明文档
2019-12-30 【更新】:framed_picture: 添加设计图片
2019-12-30 【更新】:scroll: 完善说明文档
2019-12-30 【更新】:framed_picture:添加设计图片
2019-12-30 【更新】:scroll:完善说明文档
2019-12-30 【更新】:scroll:添加电赛LOGO
2020-01-01 【更新】:book: 完善说明文档
2020-01-01 【更新】:smile:修改logo分辨率
2020-01-01 【更新】:book:完善说明文档
2020-01-08 :framed_picture: updata: controller picture
2020-01-08 :scroll: update:optimize directory structure
    [kconfig-language.txt, kconfig.txt, 全国竞赛题目清单.xlsx]
2020-01-08 :scroll: update : optimize dir
    [力臂.SLDPRT, 力臂.STL, 力臂2.SLDPRT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]
2020-01-28 :framed_picture: Add: some HMI pictures
2020-04-24 :hammer: update: readme 添加github下载过慢解决办法/ rm project快捷方式
2020-06-23 :memo: update: 更改readme图片链接
